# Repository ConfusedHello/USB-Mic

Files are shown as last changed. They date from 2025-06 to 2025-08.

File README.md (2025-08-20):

# VOXMIC - A DIY Studio-Quality USB-C Microphone
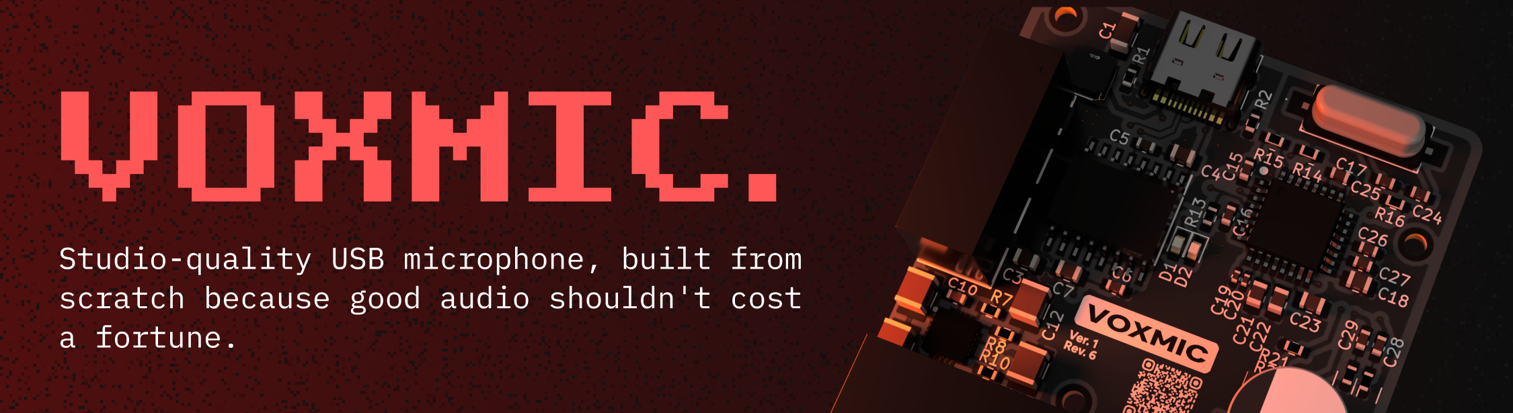
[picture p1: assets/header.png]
header

[Film lights](https://github.com/ConfusedHello/Videography-Light/tree/main) shouldn't be so insanely expensive, but you know what else shouldn't be either? A quality microphone. VoxMic is a completely DIY mic I've designed for the Hack Club [Highway to Hardware](https://highway.hackclub.com/) program!

**QUICK WARNING: This WILL NOT WORK without the bodged fixes** [*more information here*](https://www.reddit.com/r/electronics/comments/1mqmphi/comment/n9i0p1c/?context=3)

This is definitely the largest project I've ever worked on - Version 1 along has gone though **6 entire revisions** just to get to where it is now. *V2 is in the works!!!*

For details about the design process or other information, check out the [development journal](https://highway.hackclub.com/projects/ConfusedHello/USB-Mic). A local copy is available in [JOURNAL.md](https://github.com/ConfusedHello/USB-Mic/blob/main/JOURNAL.md).

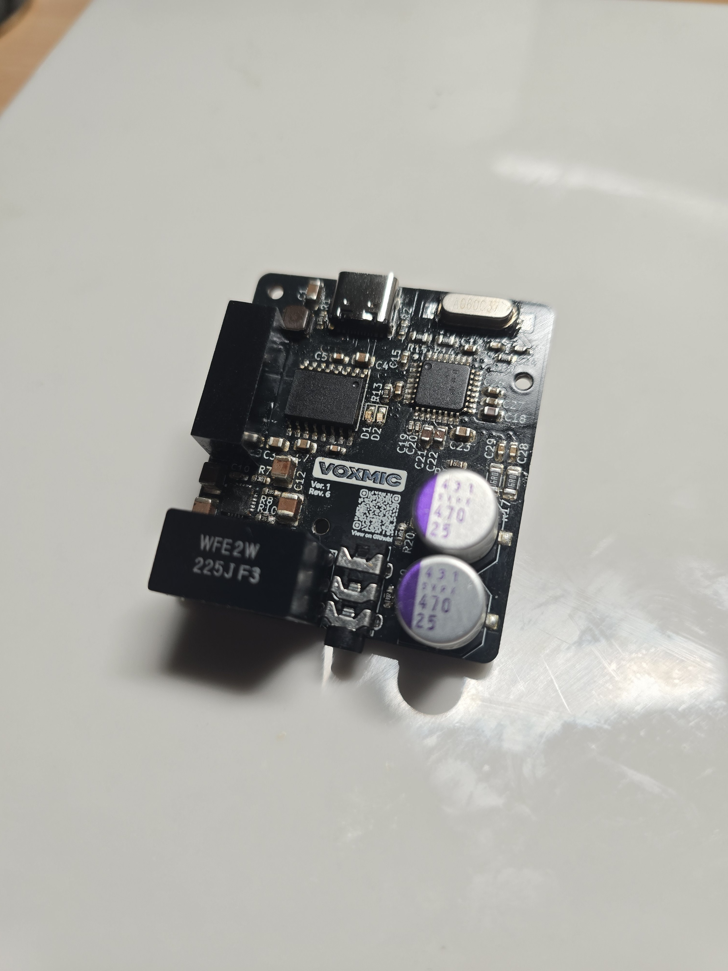
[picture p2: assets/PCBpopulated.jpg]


## The Design
Here's a quick diagram of the main components on the PCB~  
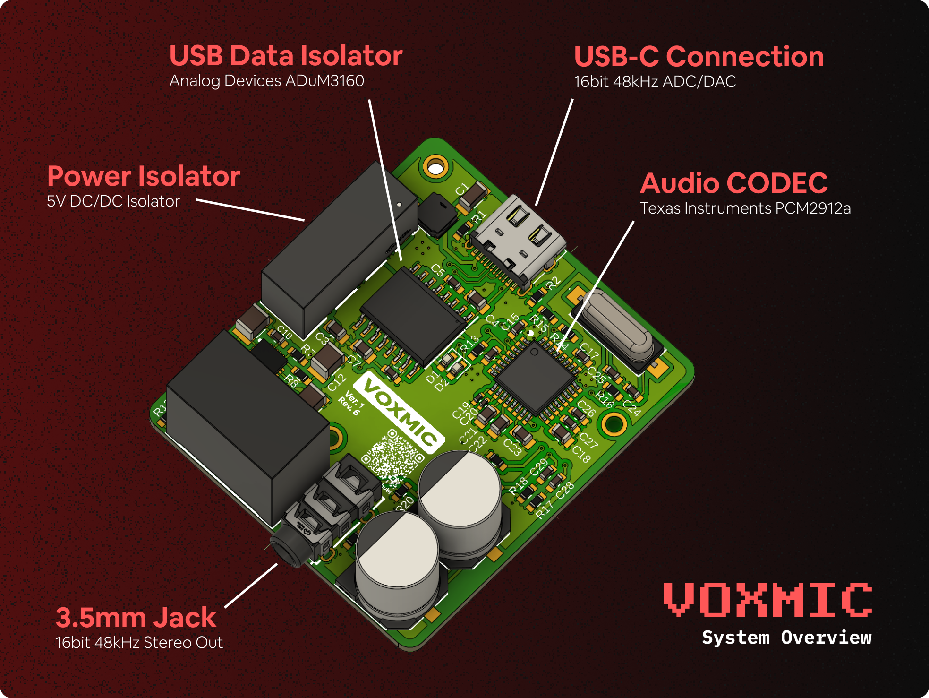
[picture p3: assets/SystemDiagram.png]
Diagram


As well as the design for the PCB!  
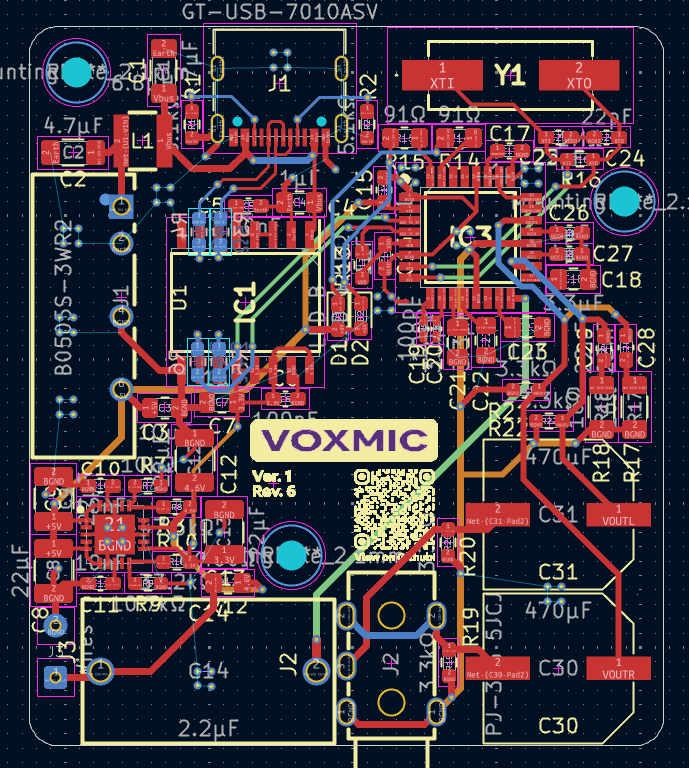
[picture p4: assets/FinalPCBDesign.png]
PCB Design

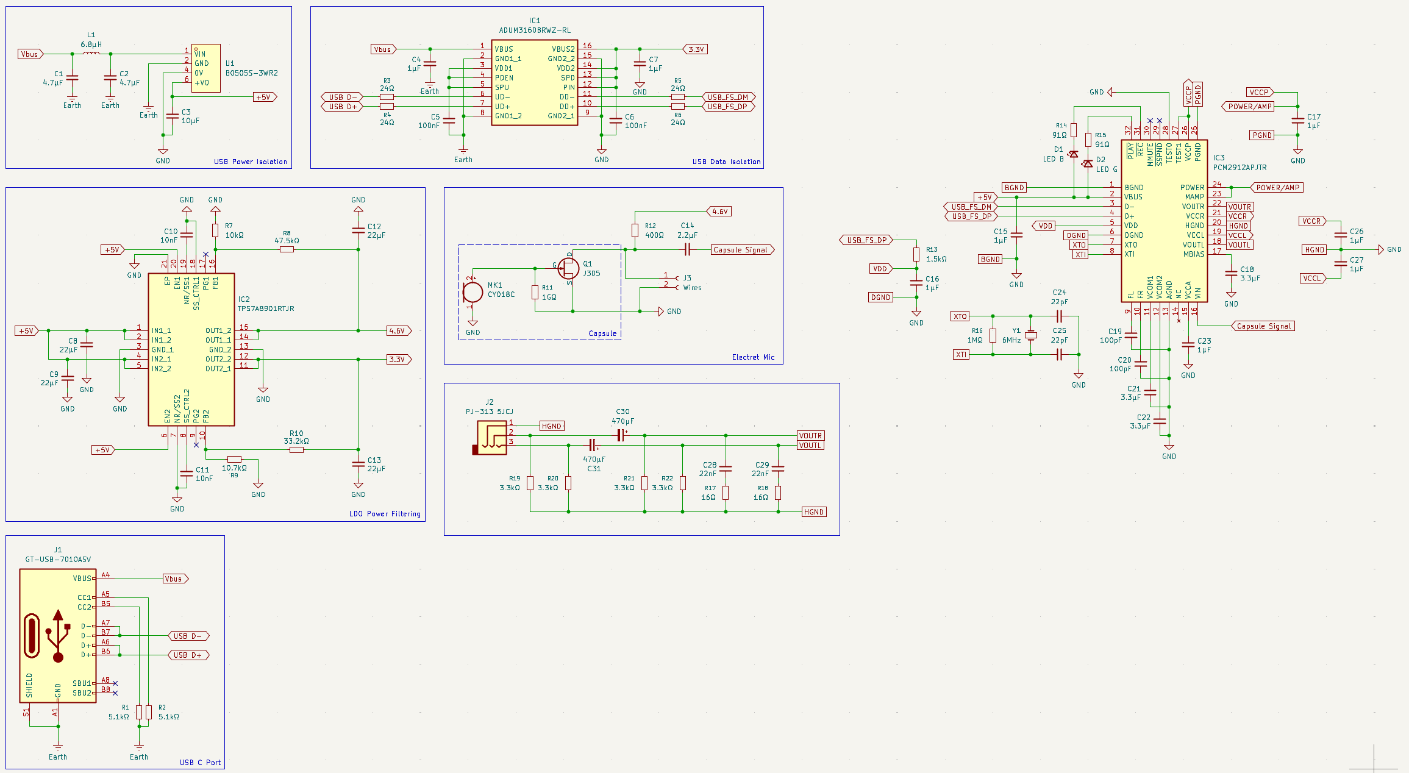
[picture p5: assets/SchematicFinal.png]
PCB Schematic


And a quick image of the case-  
<details>
<summary>Click to expand/collapse</summary>
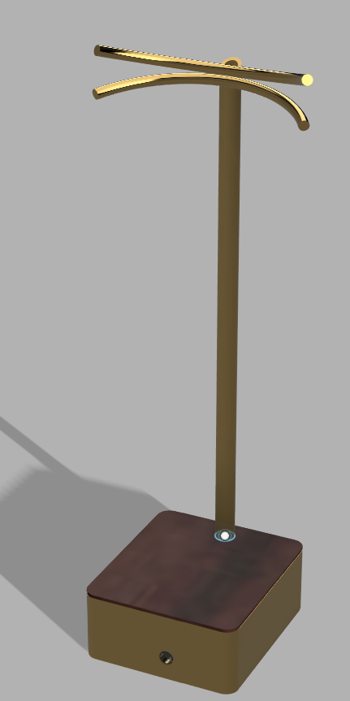
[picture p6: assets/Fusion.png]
CAD Render

</details>

## Bill of Materials
Also available in .csv format in [BOM.csv](https://github.com/ConfusedHello/USB-Mic/blob/main/BOM.csv)!

|Item |Qty.|Price (USD)|Ext. (USD)|Link |
|---|----|---|---|---|
|C14663 |100 |0.0024 |0.24 |https://lcsc.com/product-detail/multilayer-ceramic-capacitors-mlcc-smd-smt_yageo-cc0603krx7r9bb104_C14663.html |
|C21122 |50  |0.0042 |0.21 |https://lcsc.com/product-detail/multilayer-ceramic-capacitors-mlcc-smd-smt_samsung-electro-mechanics-cl10b223kb8nnnc_C21122.html  |
|C22843 |100 |0.0011 |0.11 |https://lcsc.com/product-detail/chip-resistor-surface-mount_uni-royal-uniroyal-elec-0603waf1501t5e_C22843.html |
|C23003 |100 |0.0011 |0.11 |https://lcsc.com/product-detail/chip-resistor-surface-mount_uni-royal-uniroyal-elec-0603waf3322t5e_C23003.html |
|C28323 |20  |0.0092 |0.18 |https://lcsc.com/product-detail/multilayer-ceramic-capacitors-mlcc-smd-smt_samsung-electro-mechanics-cl21b105kbfnnne_C28323.html  |
|C51205 |10  |0.0337 |0.34 |https://lcsc.com/product-detail/multilayer-ceramic-capacitors-mlcc-smd-smt_samsung-electro-mechanics-cl31b475kbhnnne_C51205.html  |
|C59782 |100 |0.005 |0.5 |https://lcsc.com/product-detail/multilayer-ceramic-capacitors-mlcc-smd-smt_samsung-electro-mechanics-cl10b105ko8nnnc_C59782.html  |
|C95841 |10  |0.0232 |0.23 |https://lcsc.com/product-detail/multilayer-ceramic-capacitors-mlcc-smd-smt_samsung-electro-mechanics-cl21b106koqnnne_C95841.html  |
|C98220 |100 |0.0011 |0.11 |https://lcsc.com/product-detail/chip-resistor-surface-mount_yageo-rc0603fr-0710kl_C98220.html |
|C100042 |100 |0.0022 |0.22 |https://lcsc.com/product-detail/multilayer-ceramic-capacitors-mlcc-smd-smt_yageo-cc0603krx7r9bb103_C100042.html |
|C105578 |100 |0.0012 |0.12 |https://lcsc.com/product-detail/chip-resistor-surface-mount_yageo-rc0603fr-071ml_C105578.html |
|C105620 |100 |0.0024 |0.24 |https://lcsc.com/product-detail/multilayer-ceramic-capacitors-mlcc-smd-smt_yageo-cc0603jrnpo9bn220_C105620.html |
|C108078 |100 |0.0012 |0.12 |https://lcsc.com/product-detail/chip-resistor-surface-mount_yageo-rc0603fr-073k3l_C108078.html |
|C153298 |20  |0.0303 |0.61 |https://lcsc.com/product-detail/chip-resistor-surface-mount_ever-ohms-tech-tr0805b400rp0525z_C153298.html |
|C178482 |1 |0.3897 |0.39 |https://lcsc.com/product-detail/polypropylene-film-capacitors-cbb_panasonic-ecwfe2w225j_C178482.html |
|C180908 |1 |2.0425 |2.04 |https://lcsc.com/product-detail/voltage-regulators-linear-low-drop-out-ldo-regulators_texas-instruments-tps7a8901rtjr_C180908.html|
|C284149 |1 |4.8716 |4.87 |https://lcsc.com/product-detail/isolated-usb-ics_analog-devices-adum3160brwz-rl_C284149.html |
|C309062 |4 |0.1383 |0.55 |https://lcsc.com/product-detail/multilayer-ceramic-capacitors-mlcc-smd-smt_samsung-electro-mechanics-cl32b226kajnnne_C309062.html |
|C454276 |2 |1.1425 |2.29 |https://lcsc.com/product-detail/polymer-aluminum-capacitors_panasonic-25svpk470m_C454276.html |
|C475497 |1 |4.3489 |4.35 |https://lcsc.com/product-detail/audio-interface-ics_texas-instruments-pcm2912apjtr_C475497.html |
|C541383 |100 |0.0011 |0.11 |https://lcsc.com/product-detail/multilayer-ceramic-capacitors-mlcc-smd-smt_yageo-cc0402krx7r8bb101_C541383.html |
|C596830 |5 |0.3215 |1.61 |https://lcsc.com/product-detail/crystals_abracon-llc-abls2-6-000mhz-d4y-t_C596830.html |
|C668607 |5 |0.0783 |0.39 |https://lcsc.com/product-detail/audio-connectors_shou-han-pj-313-5jcj_C668607.html |
|C965804 |100 |0.0044 |0.44 |https://lcsc.com/product-detail/led-indication-discrete_xinglight-xl-1608ugc-04_C965804.html |
|C965807 |100 |0.0035 |0.35 |https://lcsc.com/product-detail/led-indication-discrete_xinglight-xl-1608ubc-04_C965807.html |
|C2907018 |100 |0.0009 |0.09 |https://lcsc.com/product-detail/chip-resistor-surface-mount_fojan-frc0603f24r0ts_C2907018.html |
|C2907044 |100 |0.001 |0.1 |https://lcsc.com/product-detail/chip-resistor-surface-mount_fojan-frc0603f5101ts_C2907044.html |
|C2933225 |100 |0.001 |0.1 |https://lcsc.com/product-detail/chip-resistor-surface-mount_fojan-frc0603f4752ts_C2933225.html |
|C2933510 |100 |0.0018 |0.18 |https://lcsc.com/product-detail/chip-resistor-surface-mount_fojan-frc0805f91r0ts_C2933510.html |
|C2933610 |100 |0.0029 |0.29 |https://lcsc.com/product-detail/chip-resistor-surface-mount_fojan-frc1206f16r0ts_C2933610.html |
|C2988369 |5 |0.0805 |0.4 |https://lcsc.com/product-detail/usb-connectors_g-switch-gt-usb-7010asv_C2988369.html |
|C5153968 |100 |0.0009 |0.09 |https://lcsc.com/product-detail/chip-resistor-surface-mount_fojan-frc0603f1072ts_C5153968.html |
|C7393948 |20  |0.022 |0.44 |https://lcsc.com/product-detail/multilayer-ceramic-capacitors-mlcc-smd-smt_cctc-tcc0805x7r335k250ft_C7393948.html |
|C7500927 |1 |1.2079 |1.21 |https://lcsc.com/product-detail/isolated-power-modules_evisun-b0505s-3wr2_C7500927.html |
|C16197249 |5 |0.0579 |0.29 |https://lcsc.com/product-detail/power-inductors_yjycoin-yhnr4020-6r8m_C16197249.html |
|LCSC Shipping |1 |10.62 |10.62 |https://lcsc.com |
|CY018C |1 |30.00 |30.00 |https://www.alibaba.com/product-detail/797-Audio-CY018C-Custom-26mm-3um_1600884124178.html |
|J305 |1 |7.54 |7.54 |https://au.mouser.com/ProductDetail/InterFET/J305 |
|MOX-400231007JE |1 |10.29 |10.29 |https://au.mouser.com/ProductDetail/Ohmite/MOX-400231007JE |
|Mouser Shipping |1 |15.67 |15.67 |https://au.mouser.com |
|JLCPCB Board |1 |2.00 |2.00 |https://jlcpcb.com/ |
|JLCPCB Board Stencil |1 |7.00 |7.00 |https://jlcpcb.com/ |
|JLCPCB Shipping |1 |21.22 |21.22 |https://jlcpcb.com/ |
|Brass Tube |1 |2.21 |2.21 |https://www.aliexpress.com/item/1005005239798226.html |
|Brass Rod |6 |12.52 |12.52 |https://www.aliexpress.com/item/1005008645247905.html |
|2x100x200mm Brass Sheet|1 |17.38 |17.38 |https://www.aliexpress.com/item/1005007129408124.html |
|Steel Mesh |1 |2.80 |2.80 |https://www.aliexpress.com/item/1005003090693763.html |
|Brass Wire |1 |3.36 |3.36 |https://www.aliexpress.com/item/1005007182450013.html |
|Wood Veneer |1 |8.04 |8.04 |https://www.aliexpress.com/item/1005007643104919.html |

Total (USD): $174.57

## Notes for v2
- Capacitive touch button for muting
- Better status signalling to user
- Upgrade ADC/DAC

<hr>

Made with ❤️ by [@ConfusedHello](https://github.com/confusedhello)

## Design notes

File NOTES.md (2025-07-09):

Notes:

Get extra resistors for R11 and R12 to calibrate output
Get extra resistors for (cap biasing/supply)

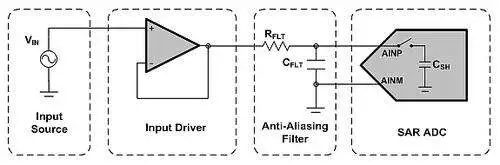
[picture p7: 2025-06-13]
assets/Proccess.jpg

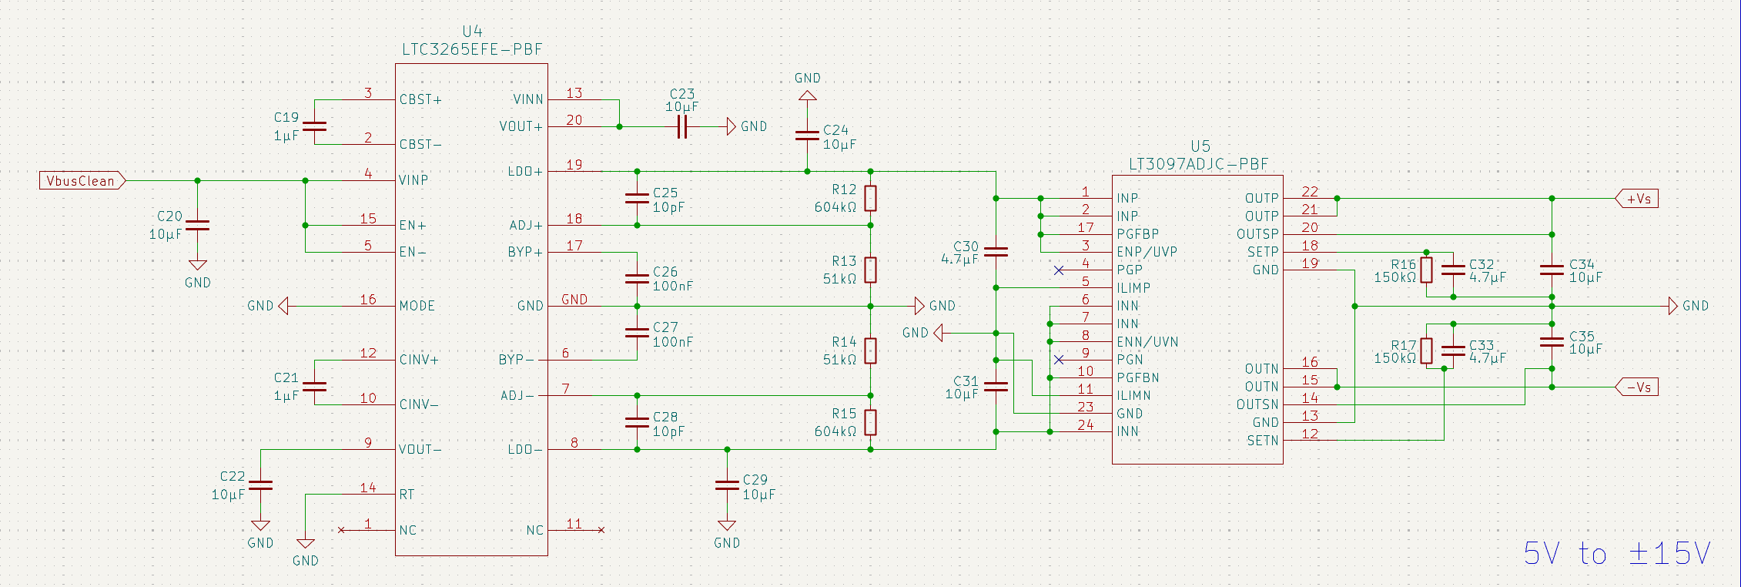
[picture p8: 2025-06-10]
assets/Rev1OPPOWER.png

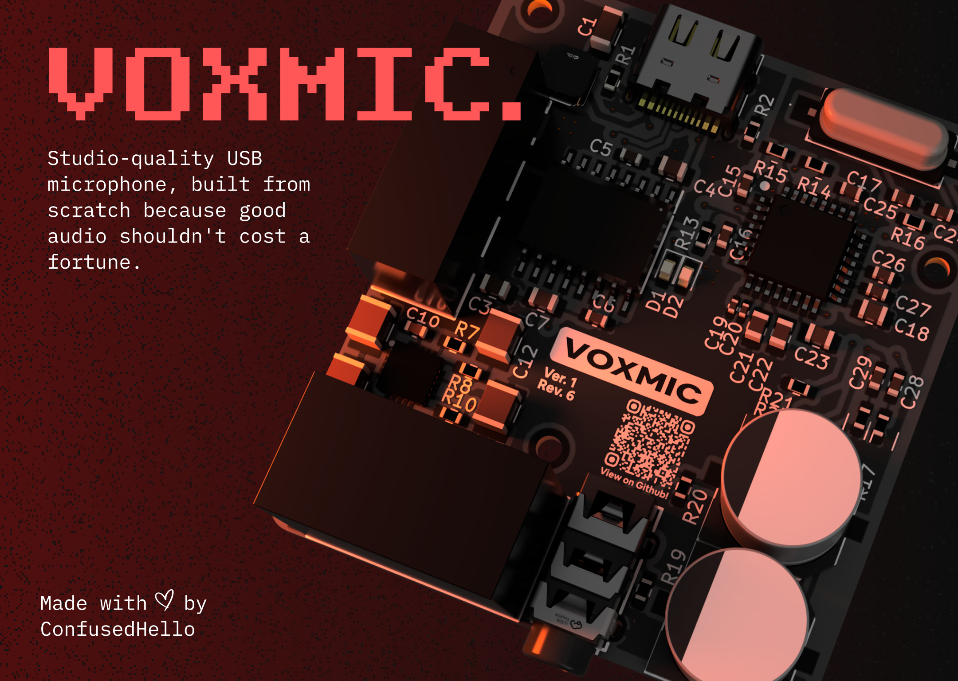
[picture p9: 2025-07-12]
assets/Slack Thumbnail.png

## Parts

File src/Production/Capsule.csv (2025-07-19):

Reference | Value | Footprint | Description | Qty | Link
MK1 | CY018C |  | Microphone Capsule | 1 | https://www.alibaba.com/product-detail/797-Audio-CY018C-Custom-26mm-3um_1600884124178.html
Q1 | J305 |  | N-JFET Transistor | 1 | https://au.mouser.com/ProductDetail/InterFET/J305
R11 | 1GΩ |  | Bias Resistor | 1 | https://au.mouser.com/ProductDetail/Ohmite/MOX-400231007JE

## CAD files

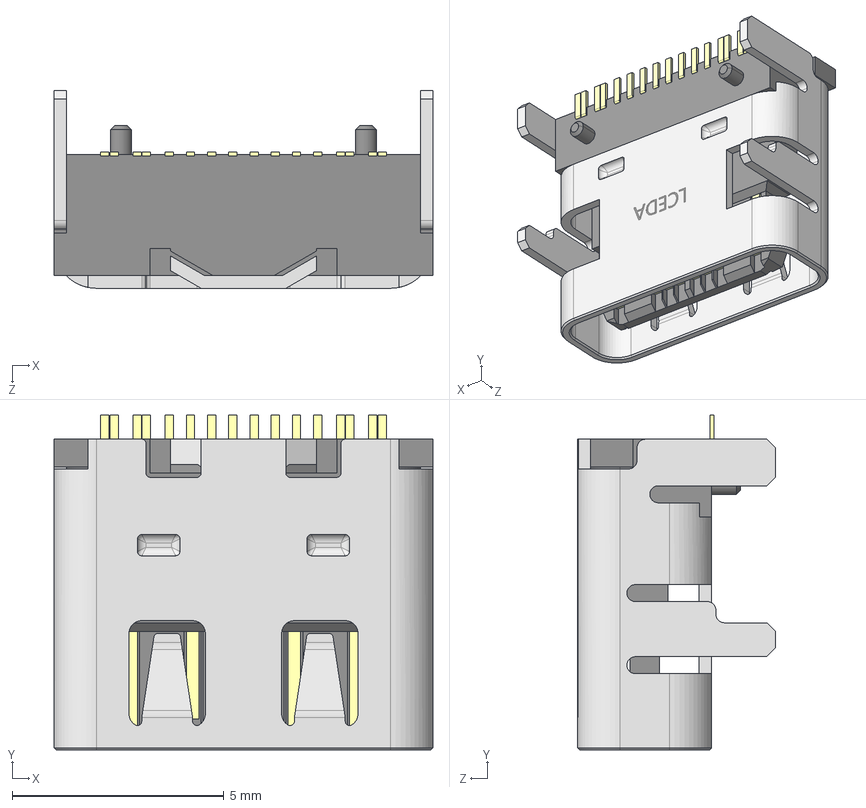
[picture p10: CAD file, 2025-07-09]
src/PCB/footprints/models/USB-C-SMD_G-SWITCH_GT-USB-7010ASV.step
8.94 x 7.90 x 4.66 mm

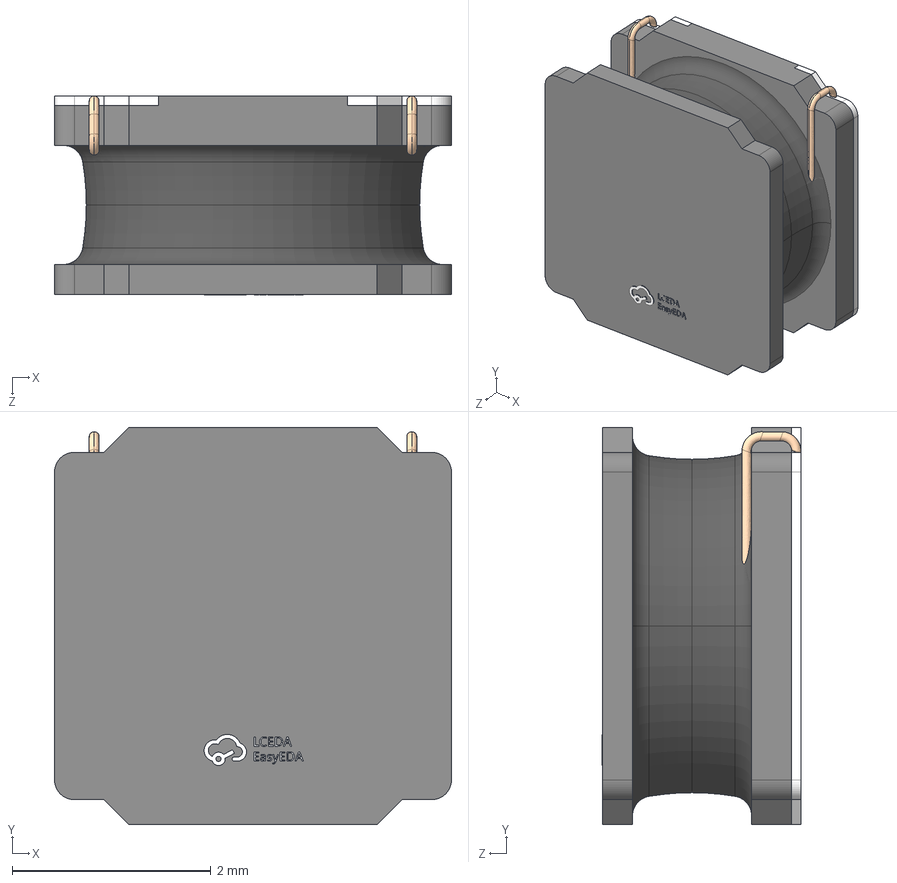
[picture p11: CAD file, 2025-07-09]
src/PCB/footprints/models/IND-SMD_L4.0-W4.0_YHNR4020.step
4.00 x 4.00 x 2.01 mm

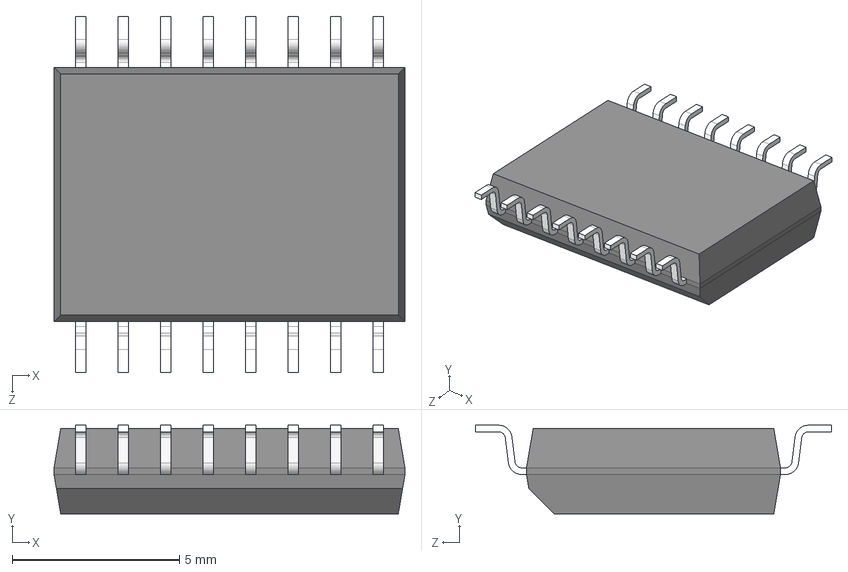
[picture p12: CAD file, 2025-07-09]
src/PCB/footprints/models/ADUM3160BRWZ-RL.stp
10.5 x 2.65 x 10.7 mm

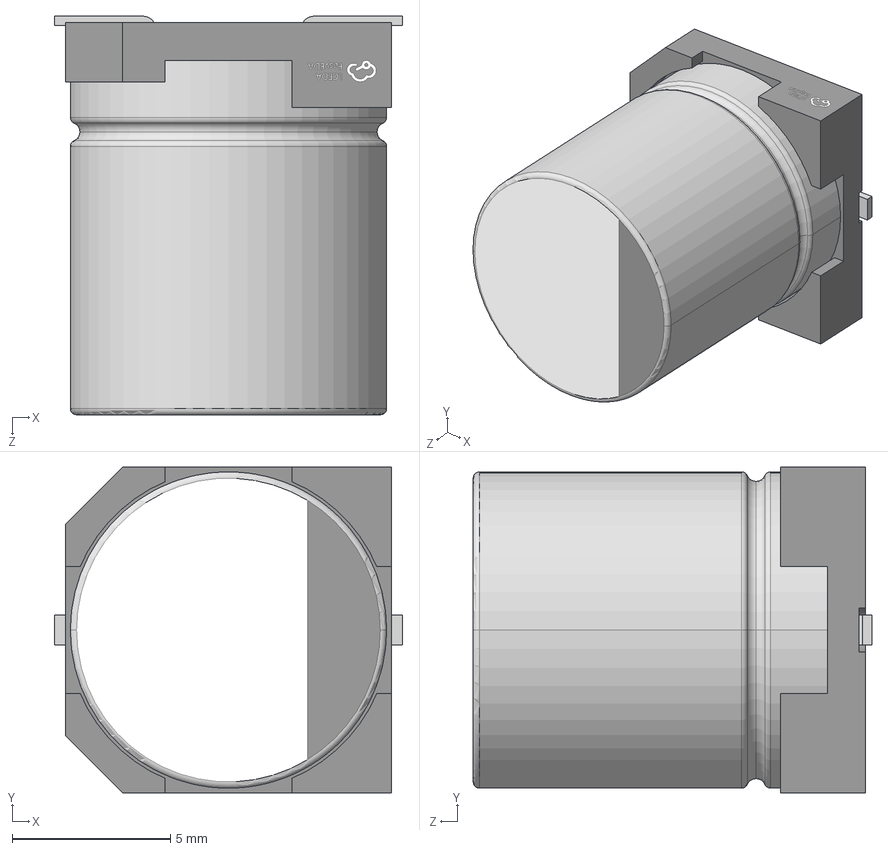
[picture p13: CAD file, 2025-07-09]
src/PCB/footprints/models/CAP-SMD_BD10.0-L10.3-W10.3-LS11.0-FD-1.step
11.0 x 10.3 x 12.6 mm

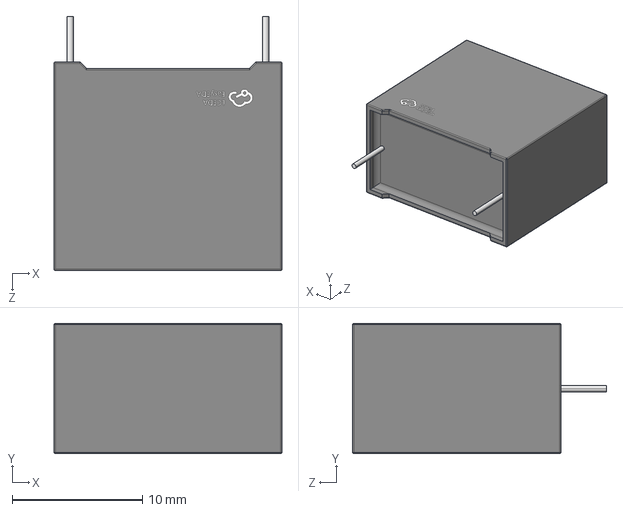
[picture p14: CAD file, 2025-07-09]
src/PCB/footprints/models/CAP-TH_L17.5-W10.0-H16.0-P15.0.step
17.5 x 10.0 x 19.5 mm

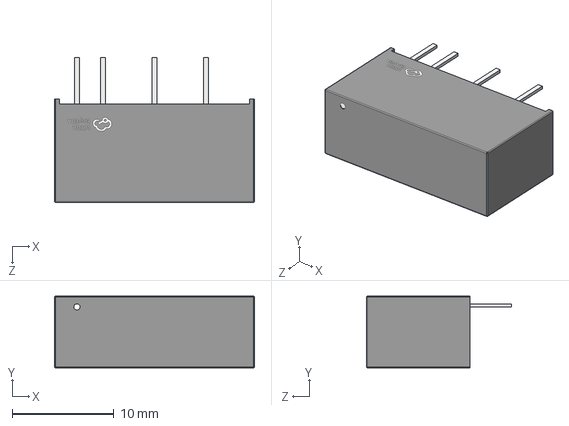
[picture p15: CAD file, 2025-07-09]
src/PCB/footprints/models/PWRM-TH_BXXXXS-3WR2.step
19.6 x 7.05 x 14.3 mm

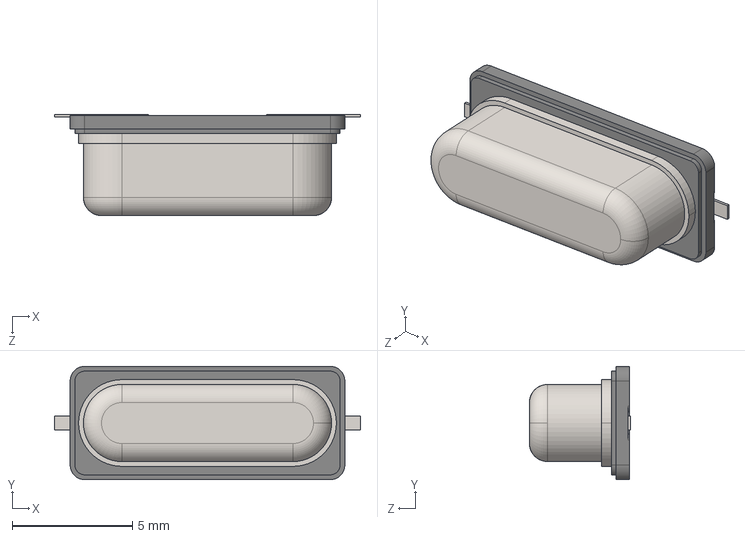
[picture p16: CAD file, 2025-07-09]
src/PCB/footprints/models/ABLS2-6.000MHZ-D4Y-T.stp
12.7 x 4.70 x 4.20 mm

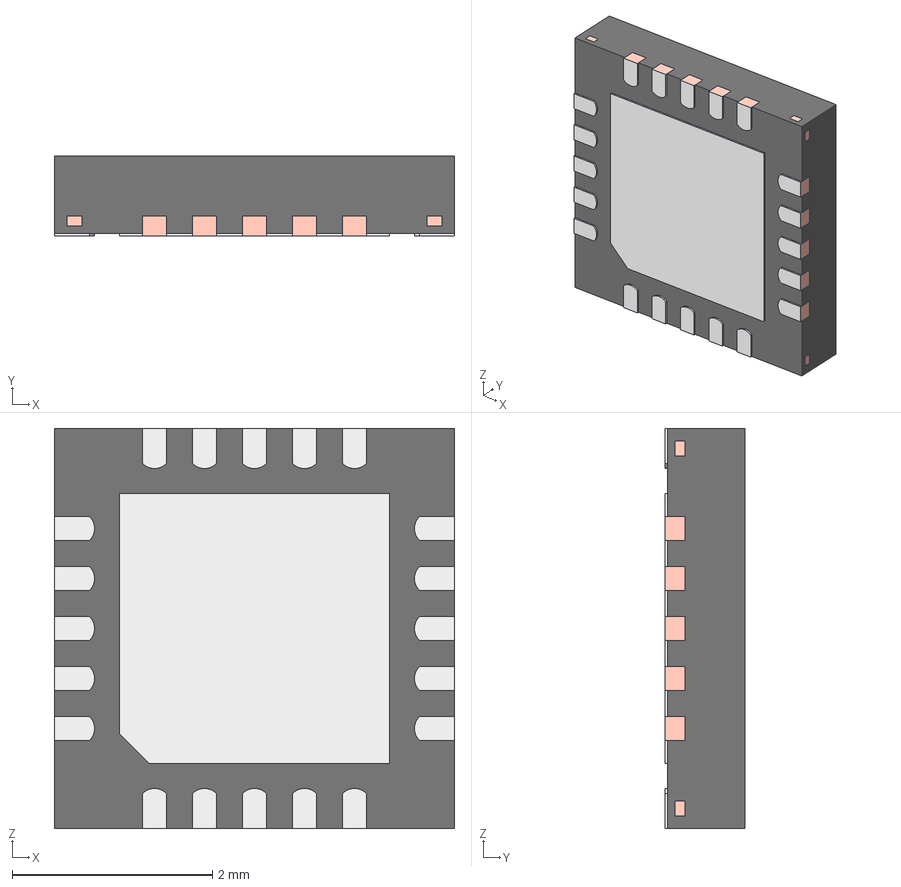
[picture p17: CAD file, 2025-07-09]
src/PCB/footprints/models/TPS7A8901RTJT.stp
4.00 x 0.8 x 4.00 mm
FRAME
PIN1_AREA

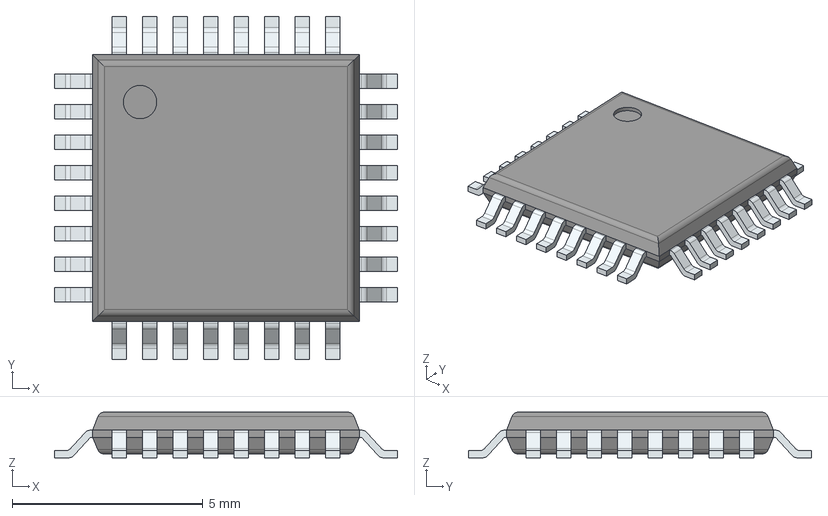
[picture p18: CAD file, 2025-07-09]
src/PCB/footprints/models/PCM2912APJTR.stp
9.00 x 9.00 x 1.20 mm
PinsArrayLR
PinsArrayTB

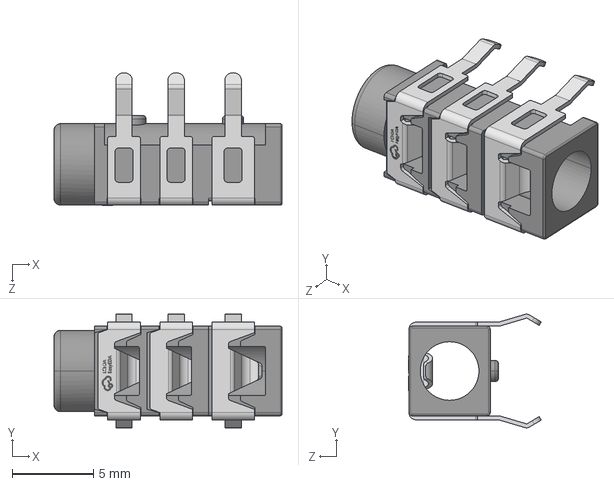
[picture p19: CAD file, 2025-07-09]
src/PCB/footprints/models/AUDIO-TH_PJ-313_5JCJ.step
14.0 x 6.98 x 8.14 mm

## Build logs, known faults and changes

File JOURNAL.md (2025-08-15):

---
title: "USB Mic"
author: "ConfusedHello"
description: "A DIY USB Microphone!"
created_at: "2024-05-22"
---

**Total time spent: 142hrs**

## August 9th
Summary: Pain.

Spent MANY MANY hours trying to solder everything together with a hot air rework station and a hot plate stolen from the chemistry department. 

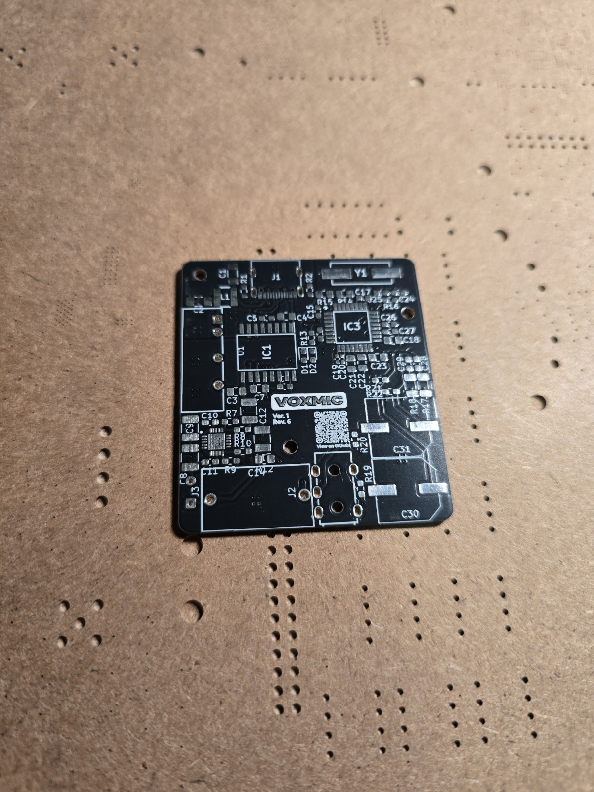
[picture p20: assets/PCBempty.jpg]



After finnicking with the dead small components for around 6 hours and screwing up 2 boards, de-soldering, and re-soldering , I plugged it in... for it to not work. USB wasn't working, and half the voltage regulator wasn't working from what I assumed was a bad join. I ended up replacing the voltage regulator with... a Xiao RP2040 (a technique I pioneered during Undercity when we had no 3.3V regs). After much pain (yes this was a very painful day), I decided that the USB isolator might be the issue, so I yanked it off, bridged the connections, and bodged a pullup to the D+ line.

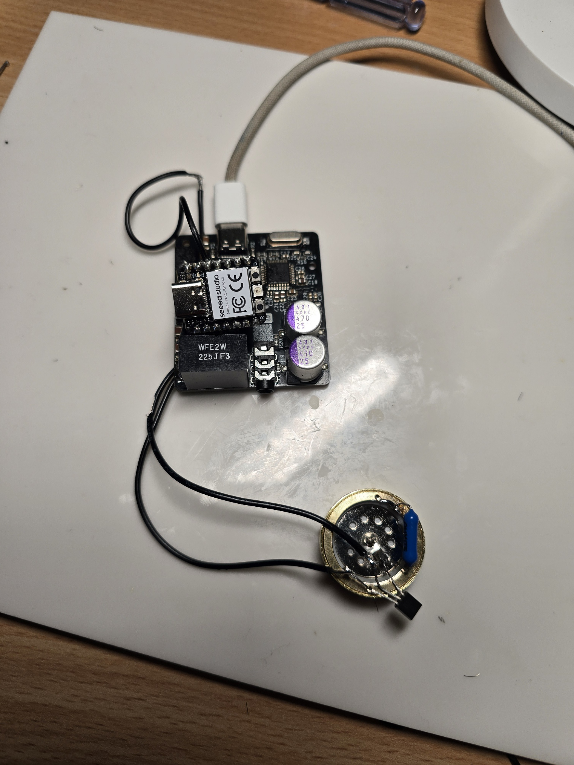
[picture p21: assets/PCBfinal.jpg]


And it... sorta works! The main issue (something I worried about during the design) was the lack of a preamp. It would not work unless I had the capsule almost *inside* my mouth. And since my brass sheet never arrived (thank you Aliexpress) I was stuck with everything but the materials for the main body. Hopefully this is okay until I can get parts!

**Time spent: 10hrs**

## July 10th
Last day before Undercity and just spent some time finalising some renders for submission!

## July 3rd-9th
Submitted another 10 point project in the last week! The last few days I've returned to working on the PCB, and finalising component selections. I've also thrown together a quick model of the case and some renders! All the lovely renders are available in the [README](https://github.com/ConfusedHello/USB-Mic) on Github!

Here's a sneak peak of the PCB~
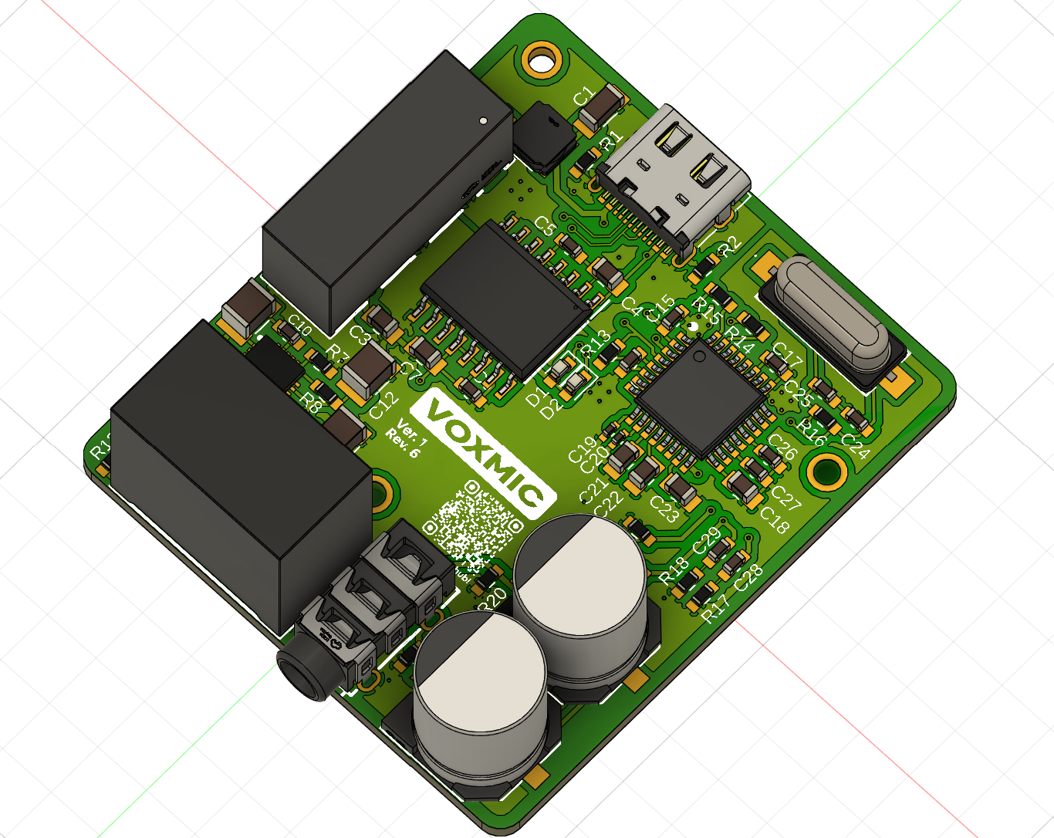
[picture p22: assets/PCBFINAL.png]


**Time spent: 16hrs**

## June 27th
HELLO AGAIN THE SCHEMATIC IS FINISHED

**Time spent: 3hrs**

## June 26th
Finished schematic, will do final review tomorrow. Have started working on selecting footprints for SMD components.

**Time spent: 5hrs**

## June 25th
One business week later - I'm partially back! My gimbal has been submitted successfully and the invite to Undercity has been received!! Spent a little time today finishing up the schematic. Realistically I'll work on the PCB tomorrow - its the final week of Term 3 so prepare for some 12hr days over the holidays.

**Time spent: 4hrs**

## June 20th
Significant progress today! However, the project will be put on hold until next Tuesday due to school tests and SAT deadlines. Progress will be journaled next week!

**Time spent: 6hrs**

## June 19th
More simulation and math. Mostly images today!!
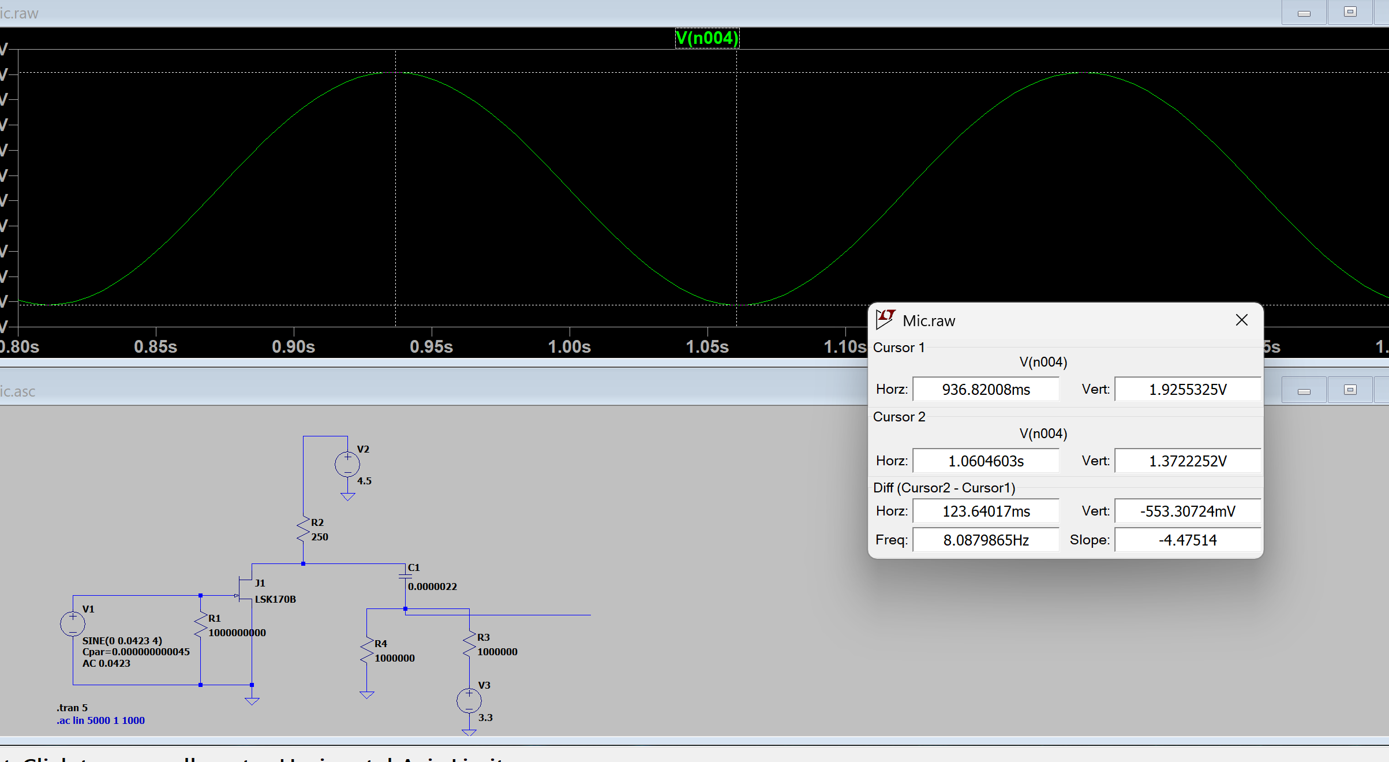
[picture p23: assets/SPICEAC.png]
SPICE

AC Analysis of the JFET output stage

With these results I made:
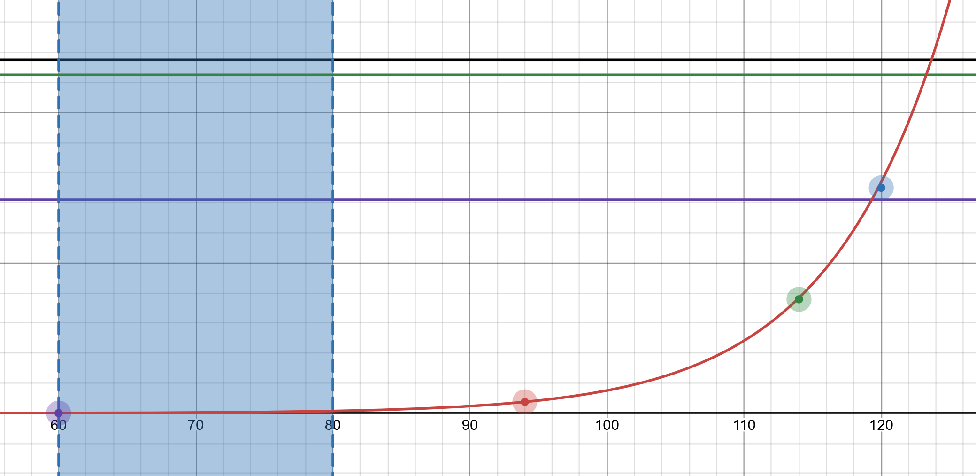
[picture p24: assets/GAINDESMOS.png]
DESMOS

Fig 1. dB to mV<sub>PP</sub> @Gain=1<sub>v/v</sub>

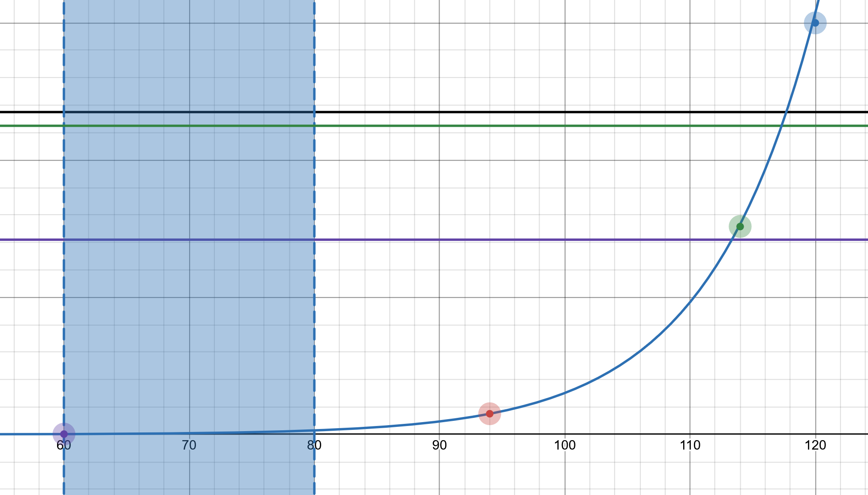
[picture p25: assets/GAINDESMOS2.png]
Desmos

Fig 2. dB to mV<sub>PP</sub> @Gain=2<sub>v/v</sub>

The purple line is the recommended max input voltage on the ADC input pins, the black line is the maximum voltage allowed, and the green is the clipping voltage of the op-amp when powered from the 4.5V supply. Honestly, I think going with no gain might actually be okay considering the +20dB amp + the -13/+36dB PGA.

Will look into choosing another N-JFET considering mine is $10... the J305 is looking pretty interesting though!

**Time spent: 10hrs**

## June 18th
Turns out making sure everything will *actually* work is difficult. Very difficult. Turns out the math behind making sure things don't explode isn't easy. In summary, over the last few days I've been revising each and every component of the microphone to make sure it's functional and well as non-explosive.

Have now moved onto consolidating values for the preamp stage. I've also done some SPICE simulations!
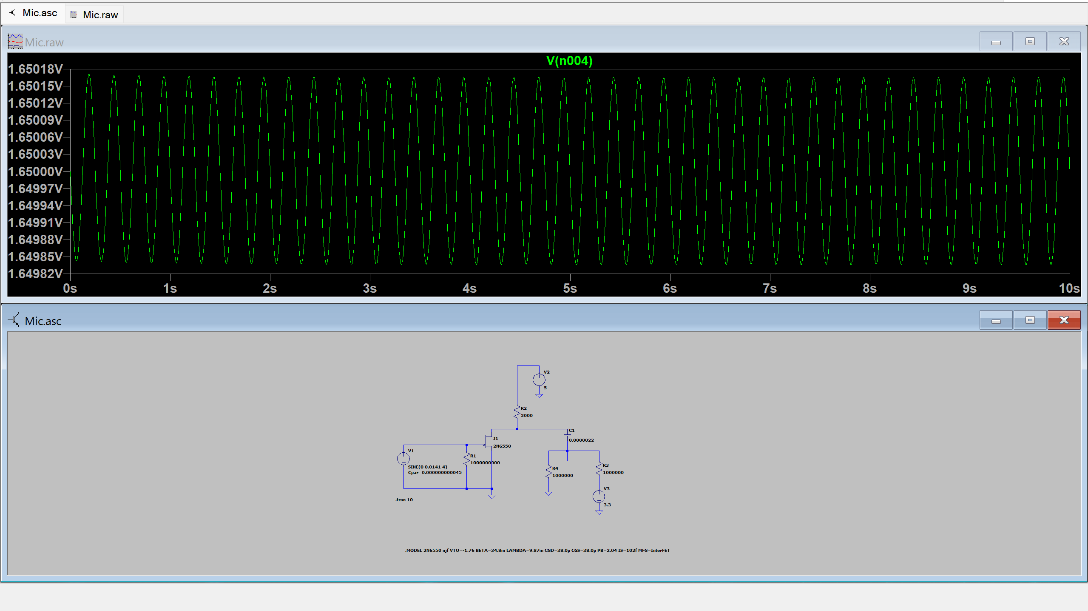
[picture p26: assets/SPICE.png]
SPICE


Busy week unfortunately - will try to work on as much as I can.

**Time spent: 8hrs**

## June 17th
Have been sick. Updates returning soon! Note to self: 14.1mV/Pa cap

## June 13th
Crazyy amount of work researching and on Rev. 4 - will finish off tomorrow. Also, the progression from Rev. 1 to 4 will be quite interesting to look back at...

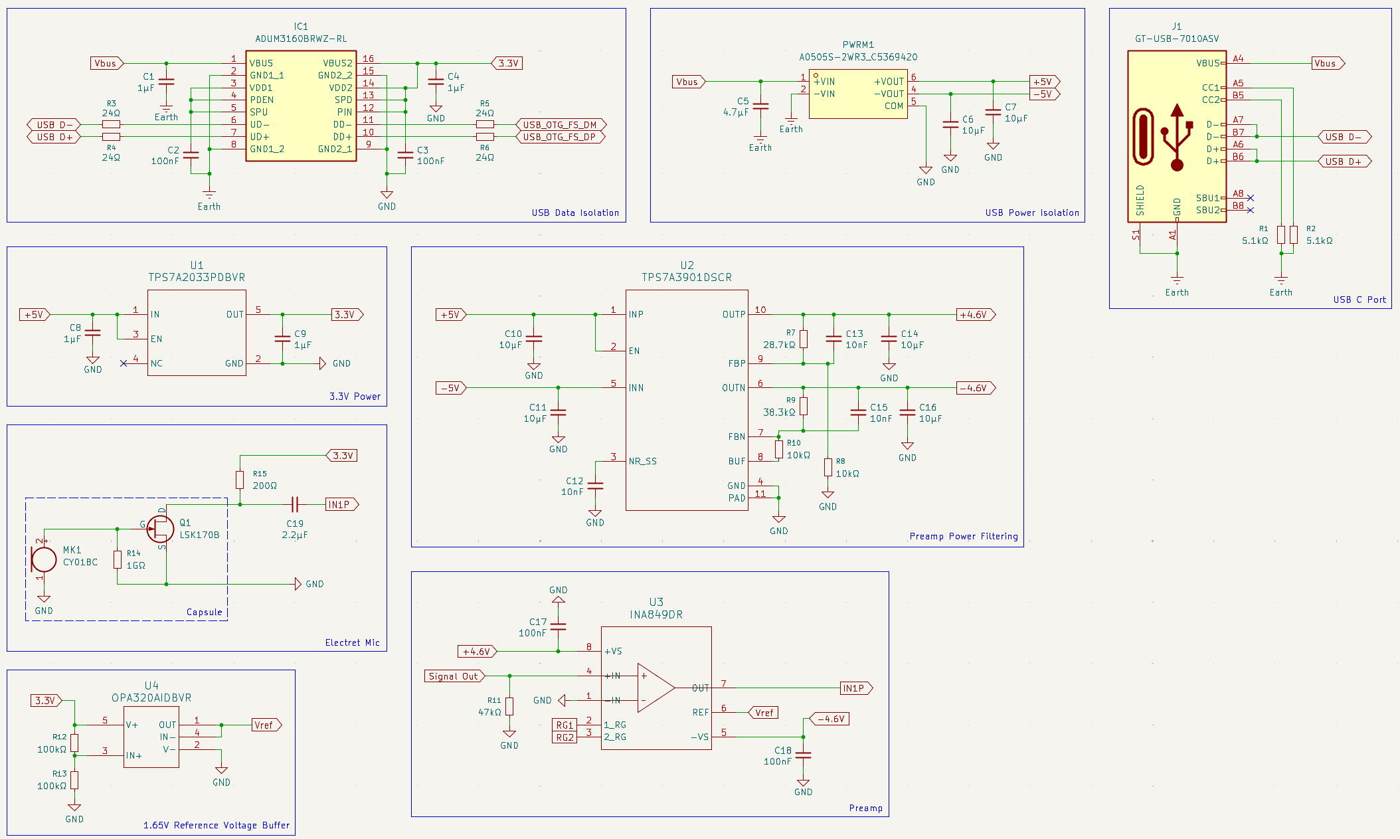
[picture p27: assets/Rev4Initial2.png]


**Time spent: 10hrs**

## June 12th
Summary of changes for Rev. 4:

- Add preamp (assumed TAA had PGA like it's I2C version - it doesn't)
- Add USB data and power isolation
- Add DC/DC converter + LDOs for preamp
- Fix floating STM32 pins
- Add ST-Link debug pins in case USB doesn't work

Hours and hours of research and reading datasheets behind this move. Also did begin working on some PCB design ideas as well as set up the STM32 CUBE IDE environment. Finishing off today's log with some screenshots.

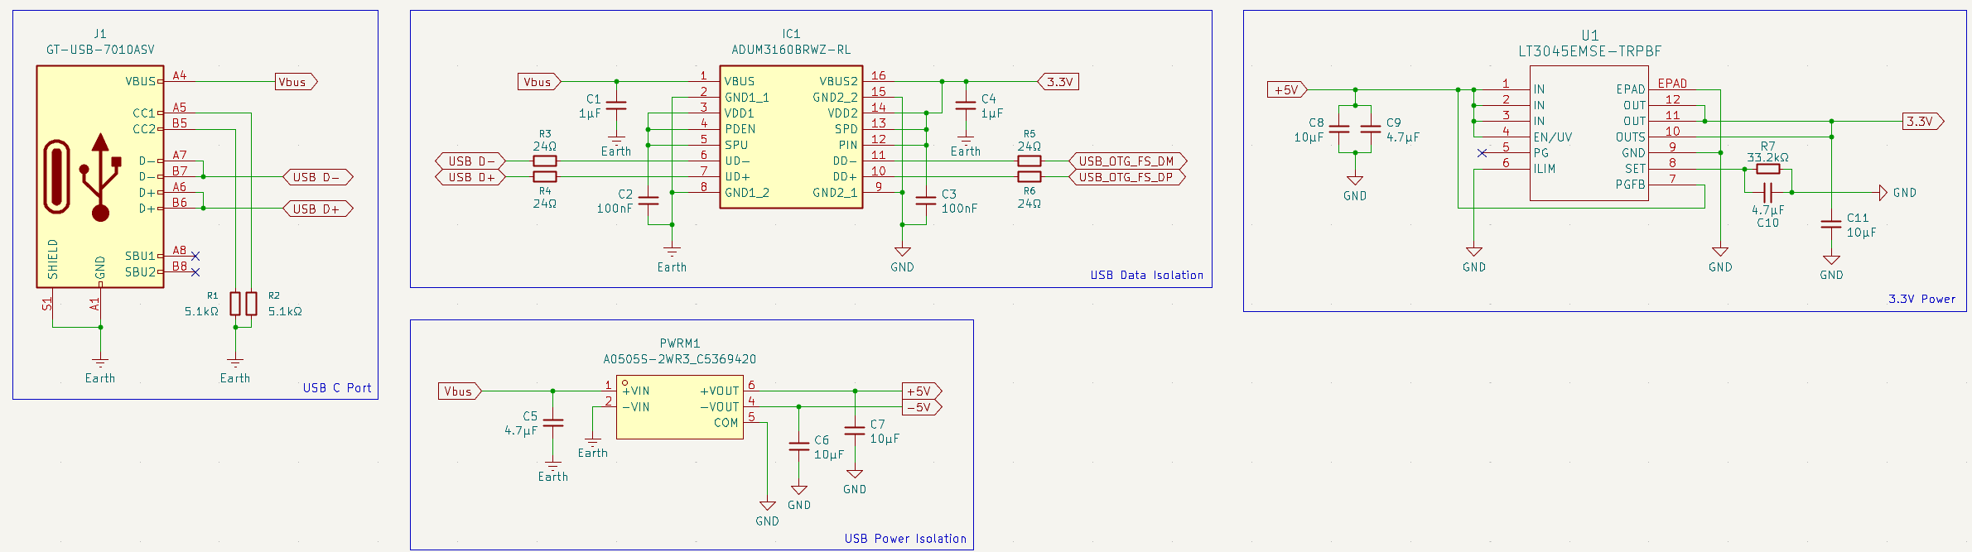
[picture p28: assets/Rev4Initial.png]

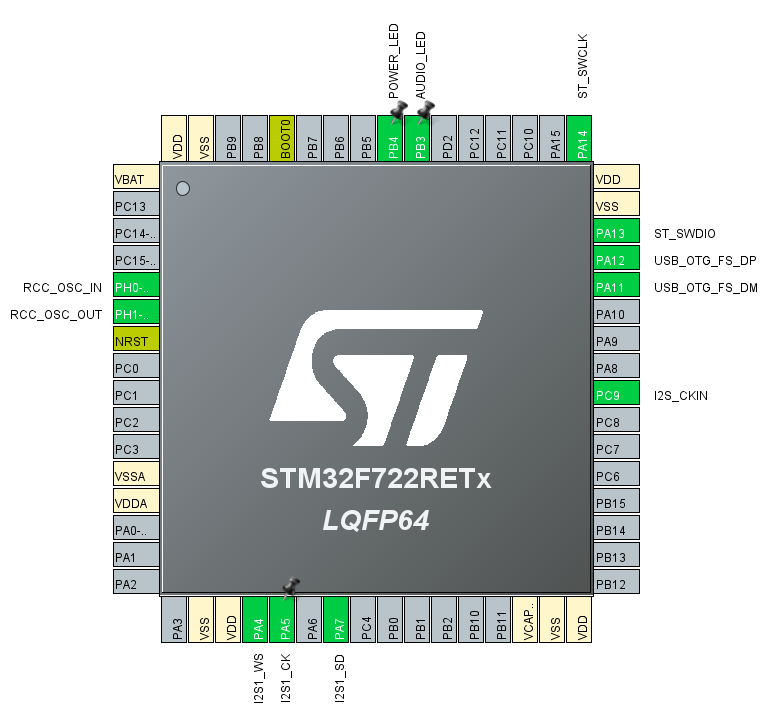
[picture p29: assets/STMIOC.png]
MCU Pinout


**Time spent: 9hrs**

## June 10th, 11th
Worked on the schematics for system today. I'm expecting Rev. 3 to be the final version of the schematic.

Thanks to the new STM32 microcontroller and ADC, the power circuity has been dumbed down even more! Since the 5V-ish Vbus only needs to go *down* to 3.3V, only the LT3045 will be needed to do all the power filtering!

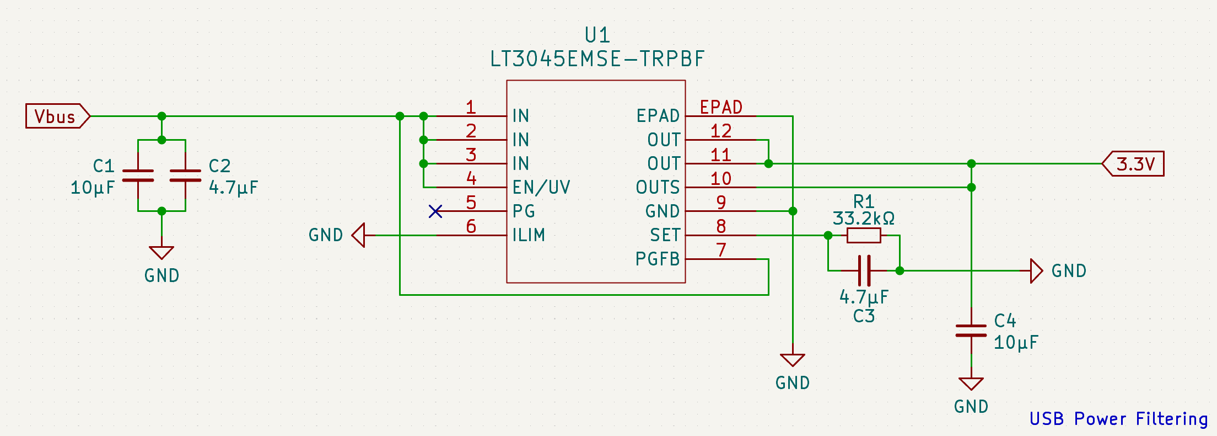
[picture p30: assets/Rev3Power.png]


Explaination soon:

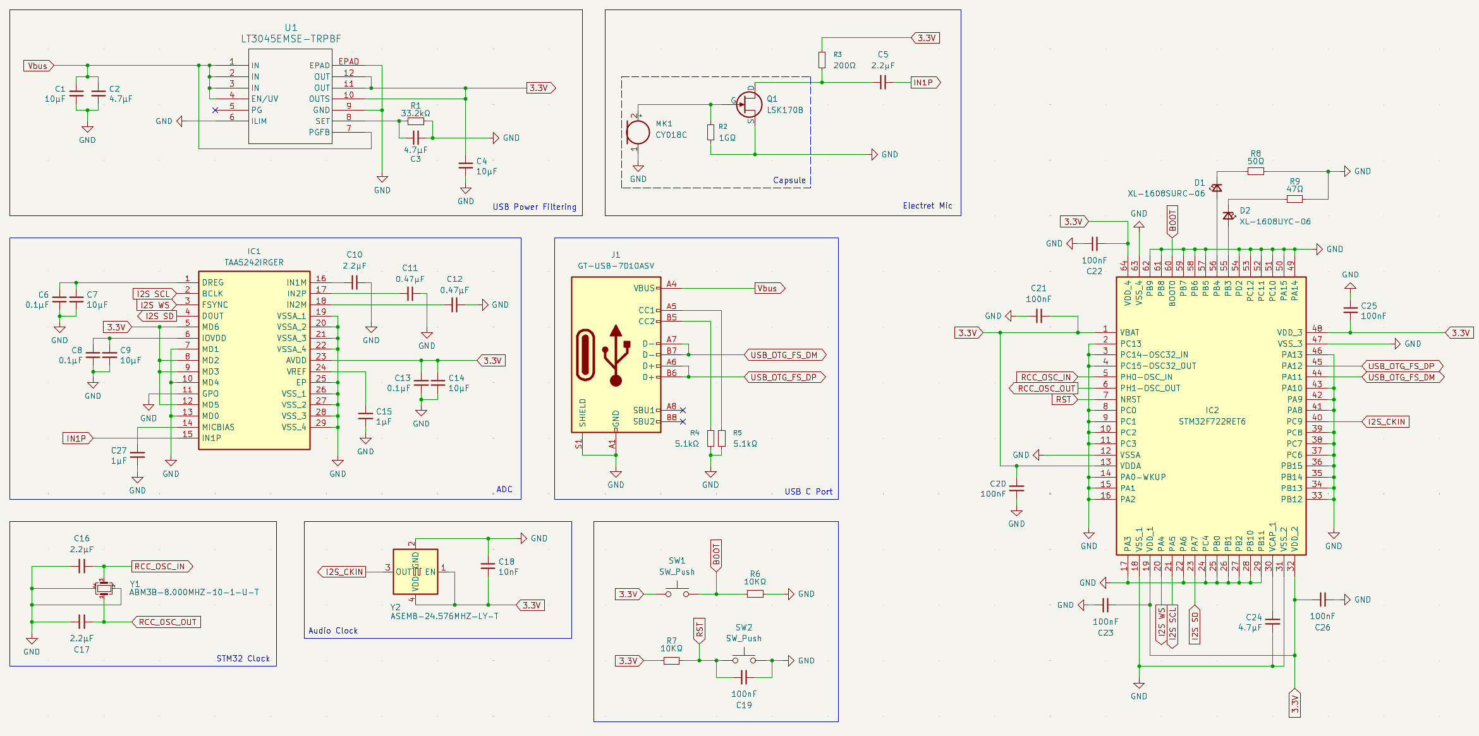
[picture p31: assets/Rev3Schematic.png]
Schematic


**Time spent: 14hrs**

## June 7th, 8th, 9th
Work over the long weekend! Lots of research (AMA) and thinking... thinking... thinking... In conclusion - time for a 3rd revision!

**Time spent: 8hrs**

## June 4th, 5th, 6th
A lot of research looking for USB-chips..., STM32 Audio Class implementations... So much time, so much pain.

IN SUMMARY

- XMOS (the standard higher-end audio chip company) IS EXPENSIVE AND PAINFUL TO USE. Absolute no-go.
- ADC/DAC USB chips from realtech, cmedia, cirrius etc. which are typically used in laptops aren't very easy to get a hold of... and also kinda suck. And outside of these, USB devices are non-existent.

As such, we'll be going the STM32 route! There's middleware for USB Audio as well as I2S communication, so the programming should be... significantly challenging but not impossible.

**Time spent: 9hrs**

## June 2nd, 3rd
Reviewed the schematics over the last two days. A few changes have been made so, I figure this is officially Rev. 2

Firstly, the preamp+capsule didn't actually make any sense (TI what are you doing) so I've transitioned to a more traditional preamp. I've also added in variable pickup using a two switches connected to the front and back diaphrams.
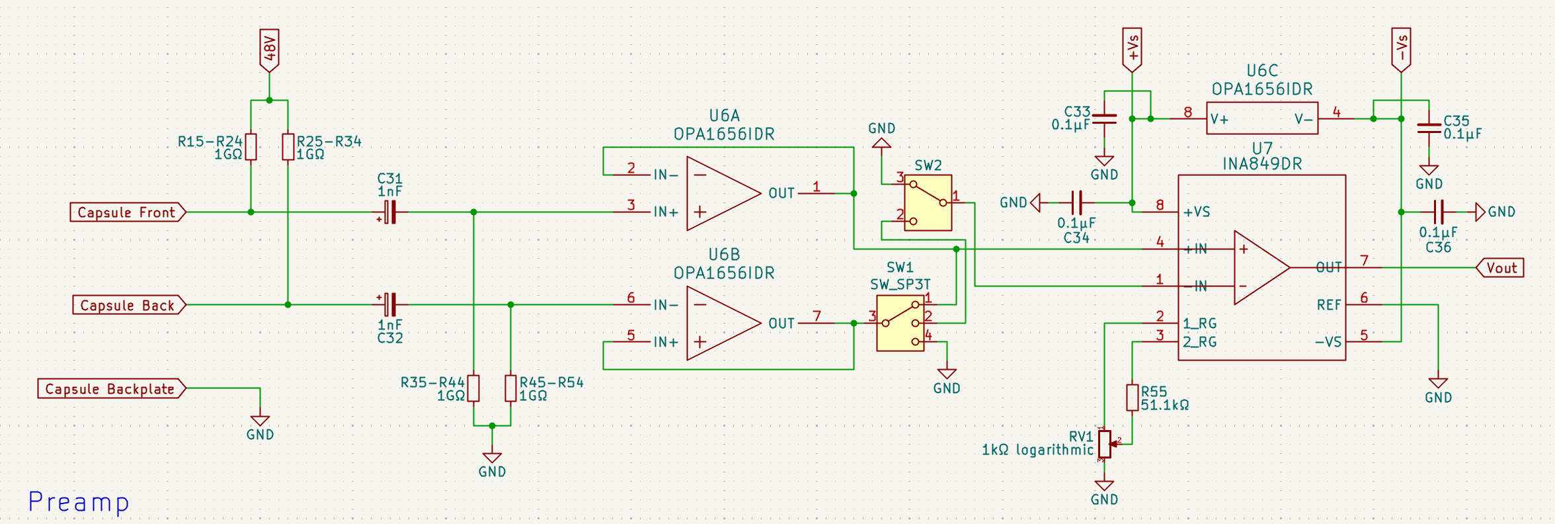
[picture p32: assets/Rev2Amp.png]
 

Secondly, I caught *more than a few* miscalculations in the resistor values for some of the power components and fixed them. I've also moved from using two LT4035's to only 1 as after calculating the total power draw, one will be sufficient.
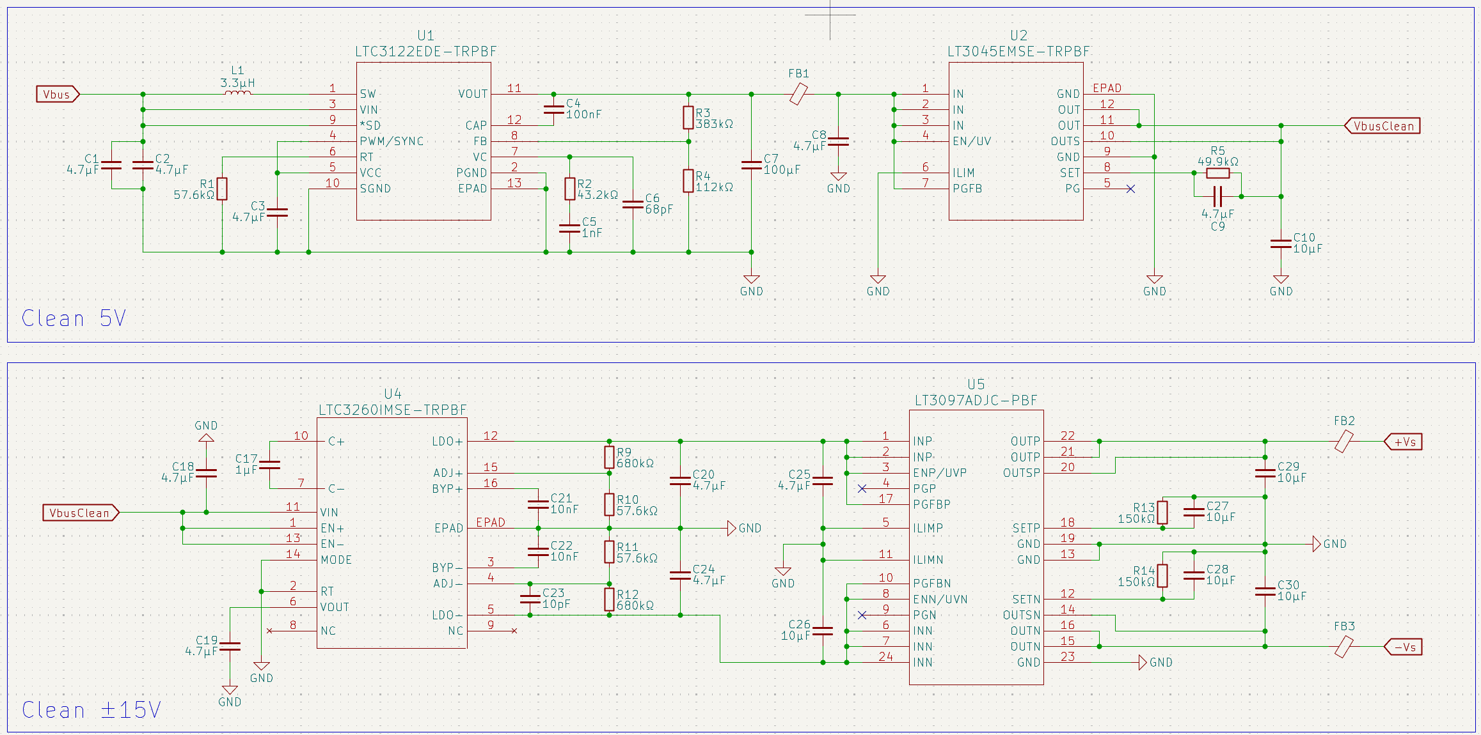
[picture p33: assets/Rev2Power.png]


The bigger change, however, is a with the ADC. I've decided to completely remove the PCM2900. Its just not good enough, and it would be a shame to pair it with the analog front-end. The new plan is to use a dedicated ADC, then over I2S or some other protocol with a STM32 or similar, bridge it to USB. Which means the project just got a lot more complicated-

**Time spent: 3hrs*

## June 1st
Some more work on the mic today! Attempted implementing the PCM2900 to take the line-level signal and output USB. I've also printed (yes printed) the datasheets for all my power components so I can go through and check for errors sometime next week.
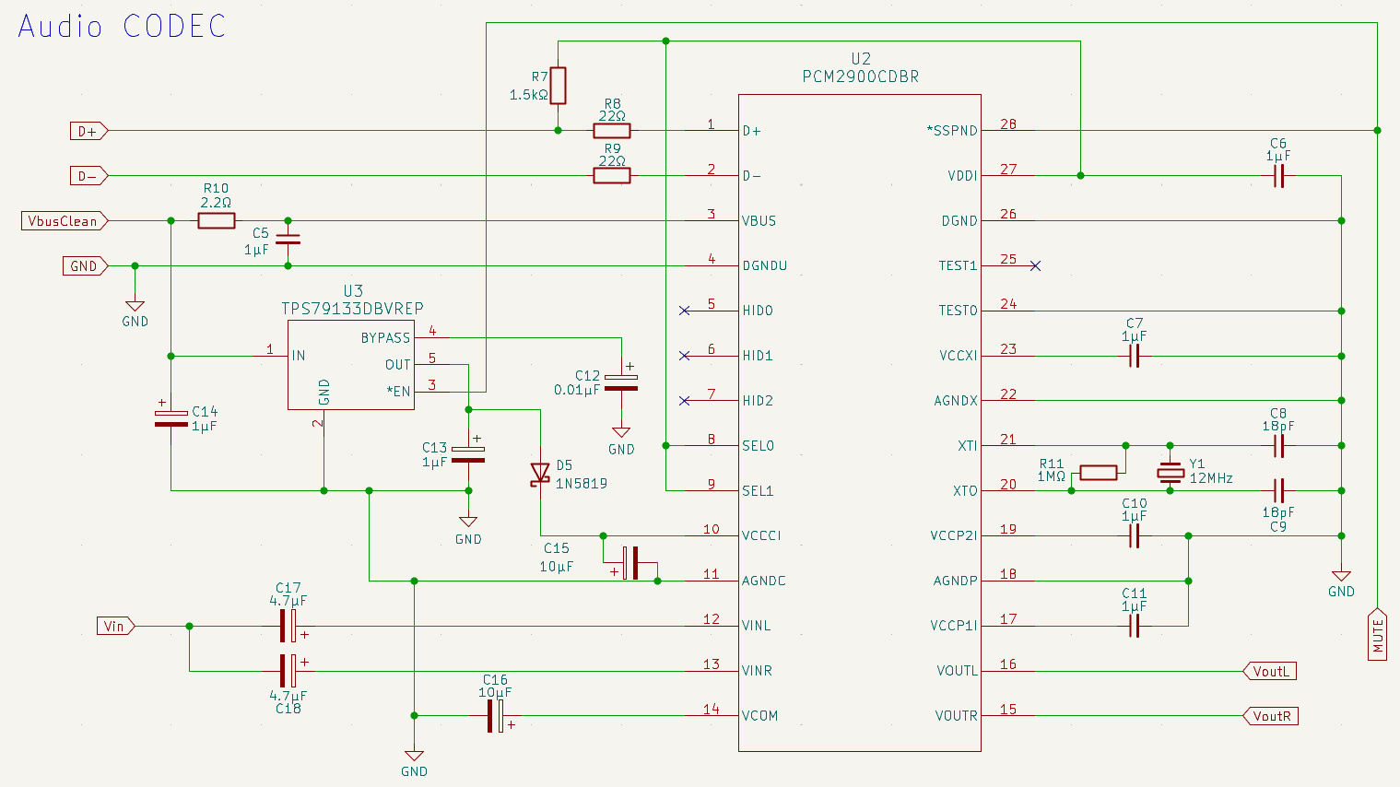
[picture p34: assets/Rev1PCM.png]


**Time spent: 1hr**

## May 28th, 29th, 30th
A bit of work on the schematics over the last few days - been caught up with Hackpad as well as my DLSR Gimbal though. First up was the capsule and preamp - I primarily looked at some example implementations in TI datasheets. Here it is!
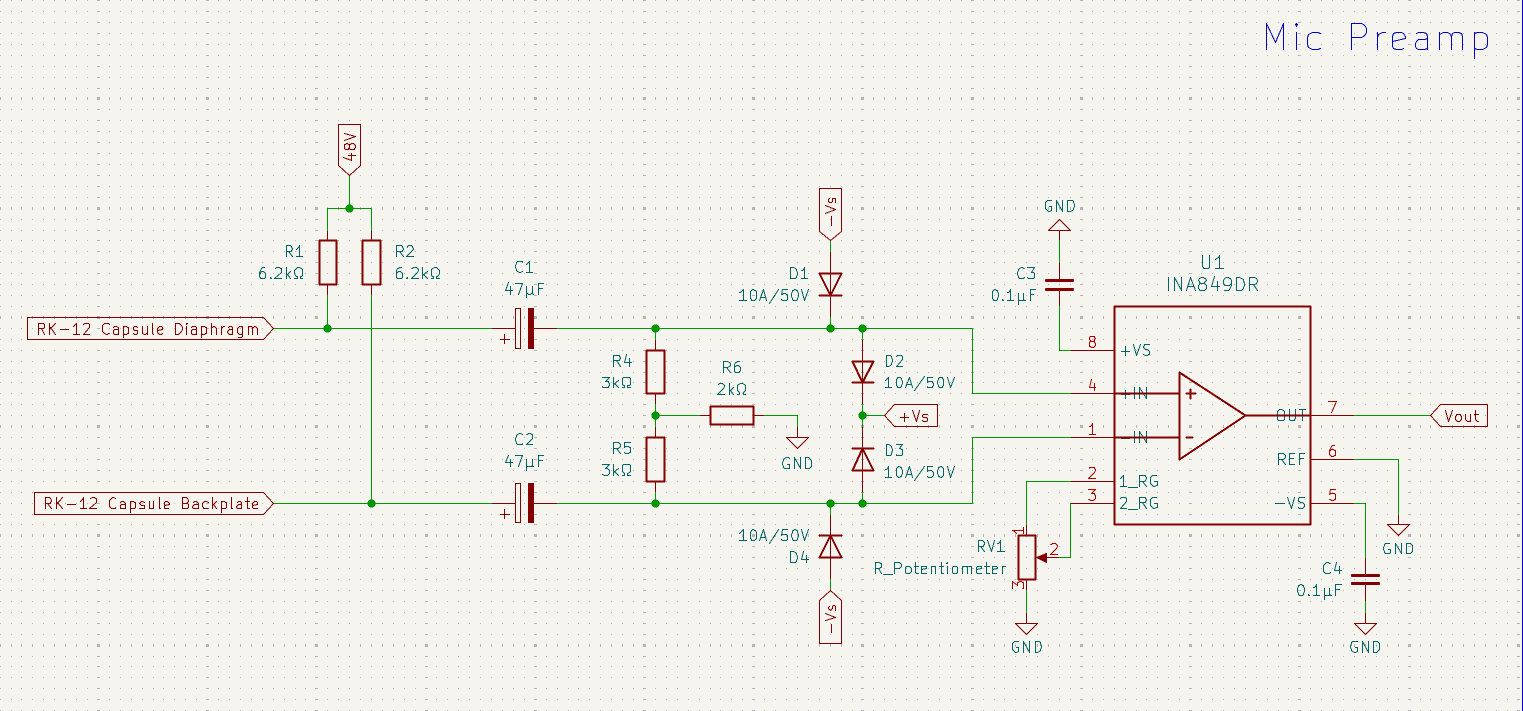
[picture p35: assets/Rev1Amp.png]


Still not too sure how much of it works... I'll keep it the same as the TI implementation for now until I know how any of it works. 

Next up was the power circuitry - it's a bit of a headache but I'll try to explain the basics of each stage.

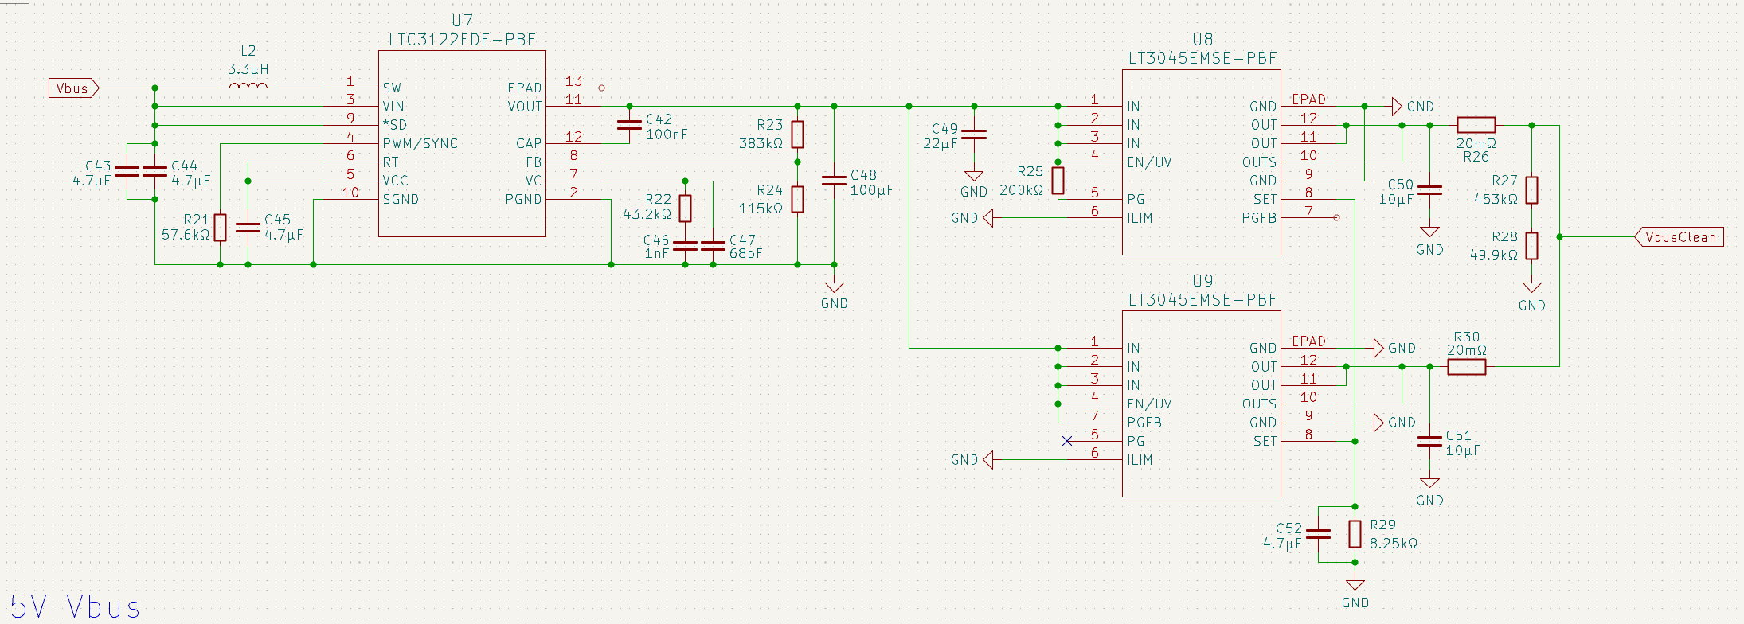
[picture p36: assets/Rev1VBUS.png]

First up here are the components to filter the noisy (and not actually 5V) Vbus from the usb host (laptop). The basic outline for this stage is to take the 4.45V-5.25V, boost it up to slightly over 5V, and the drop it to a nice and clean 5V with a LDO.

Schematic
VERY SIMILAR TO THE ONE ABOVE. Takes the clean 5V in, and spits out ±15V (just think of it as 30V but GND is now in the middle) which does through a LDO that supports a pos and neg voltage.

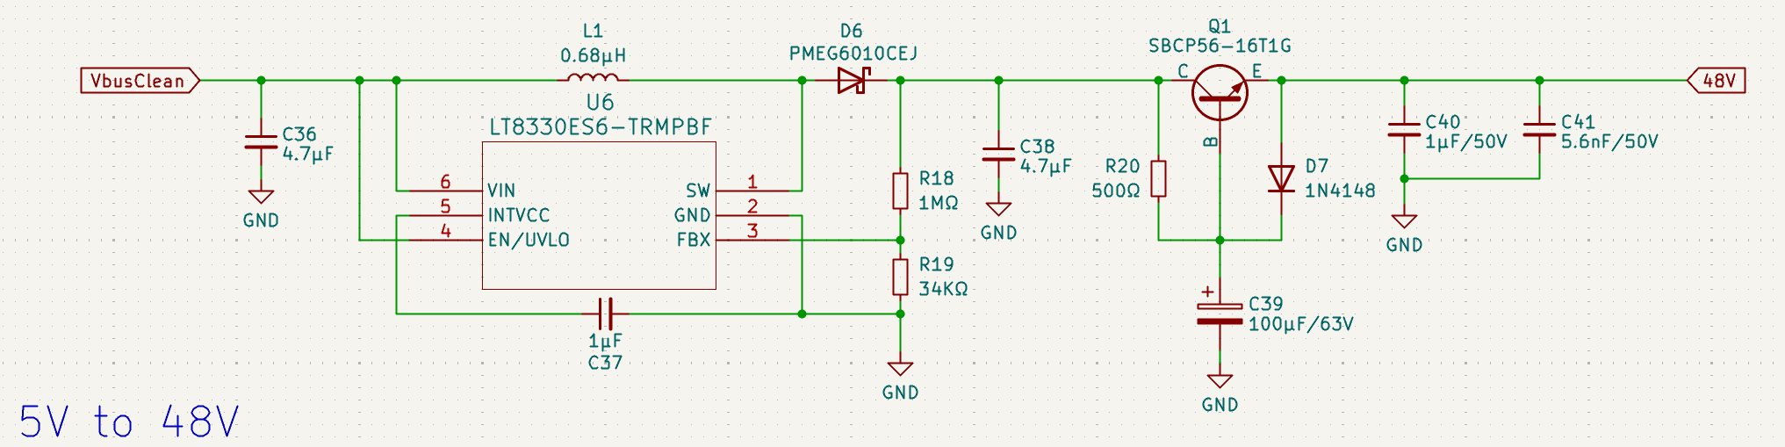
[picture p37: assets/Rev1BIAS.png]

This one's actually from a old THAT Corp. blog post, saves some trouble looking for components (saving a little cost) while also providing me with a schematic I know works! 

Overall, progress going pretty well~

**Time spent: 8hrs**

## May 26th, 27th - Final research
Yes I've run out of title ideas...

I'm combining multiple days in the logs because I've just started another project [here](https://highway.hackclub.com/projects/ConfusedHello/DLSR-Gimbal) but we'll make sure to keep going here!

Majority of the last two days has been finding suitable components for the main stages of the mic board. This took so long I feel like I've memorised parts of the TI and AD websites by now. The components I've chosen for now are:

- INA849DR amp
- LTC3265 + LT3097 for 5V to ±15V, then a ±15V LDO
- LTC3122 + LT3045 for Vbus to 5V, then a 5V LDO
- LT8330 for 48V

Interestingly, something I found while scouting the TI website is the PCM2900. It's a single chip that combines an ADC and a USB controller. It's slightly limiting at 16bit/48kHz but let's go with it for now.

**Time spent: 8hrs**

## May 24th, 25th - Let There Be 48V
Finished the initial research phase. so much information on power supply design/components. Powering sensitive analog circuits from a noisy 5V USB line (and oml it's so much worse than I expected) is a major challenge. For PSU components, values such as Power Supply Rejection Ratio (PSRR) etc. are crucial for a clean sound. 

In summary, the power will go through a buck/boost converter to get a stable 5V, and then will be followed by a low-dropout (LDO) regulator to clean it up. The LDOs I'm looking at (LTC3045 for example) have a very low noise level to ensure the preamp gets the clean power it needs to perform well.

As the 48V for the bias voltage from 5V requires a significant step-up, I found a great reference design in an old blog post from THAT Corporation that uses an LTC boost controller.

Design begins tomorrow!

**Time spent: 10hrs**

## May 23rd - And Then God Said, Let There Be Sound
Today's research was focused mostlyy on taking the output of the capsule and turning it into a line-level signal through something called a preamp stage. As a true condenser capsule has an incredibly high output impedance (typically in the GOhm range), and has tinyy fuctuations when in use, you need to amplify the signal before processing it digitally.

Most of the day was spent reading application notes from TI, Analog Devices, and THAT Corp (yes, THAT one) and looking into some existing DIY microphone designs, either way I'm pretty sure I'm in for a world of pain. Already thinking of some components for the device.

**Time spent: 5hrs**

## May 22nd - In the Beginning, There Was Nothing
Beginning work on the project today! The main inspiration is the DIY Perks USB Mic, but I want to go a step further and build one for myself while understanding the theory behind a mic. First decision - the capsule. I've settled on a RK-12 style knockoff off AliExpress that looks promising.
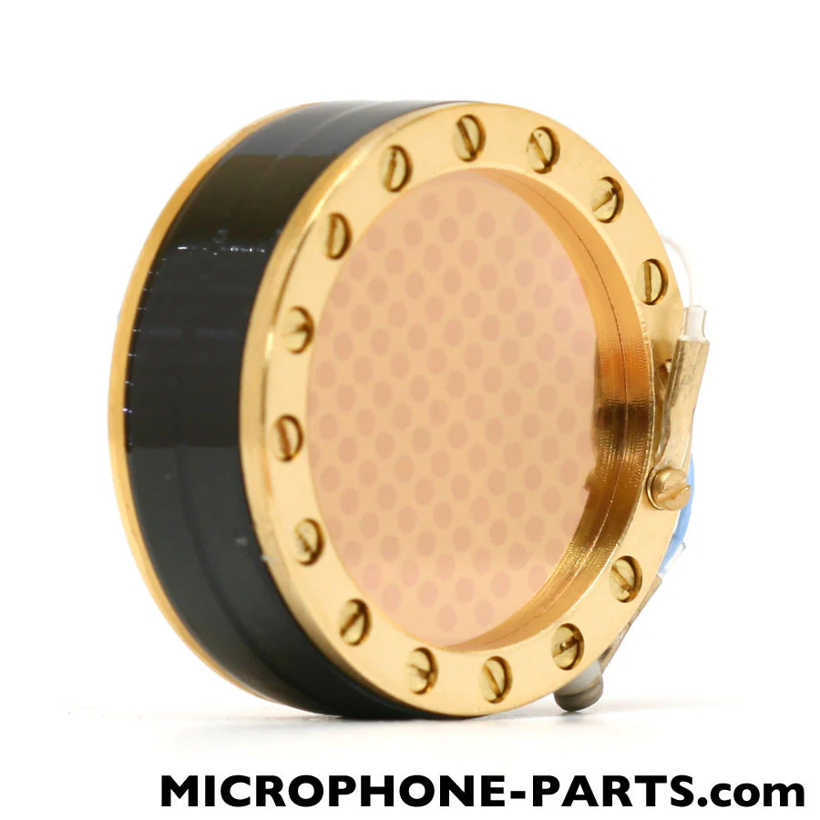
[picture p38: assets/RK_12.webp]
RK-12 Capsule


It's dual diaphram (as far as I can tell) with a single blackplate in the middle. This does mean however I will be building proper a high-voltage bias supply and proper preamp.

So what's the difference between my project and your standard DIY Mic? Well, it's going to be USB, while majority of DIY mics are XLR (saves the pain of USB stuff and other amp issues). Anyways, I'm expecting the next few days to be insane amounts of research considering... mic design has quite the learning curve apparently.

**Time spent: 4hrs**

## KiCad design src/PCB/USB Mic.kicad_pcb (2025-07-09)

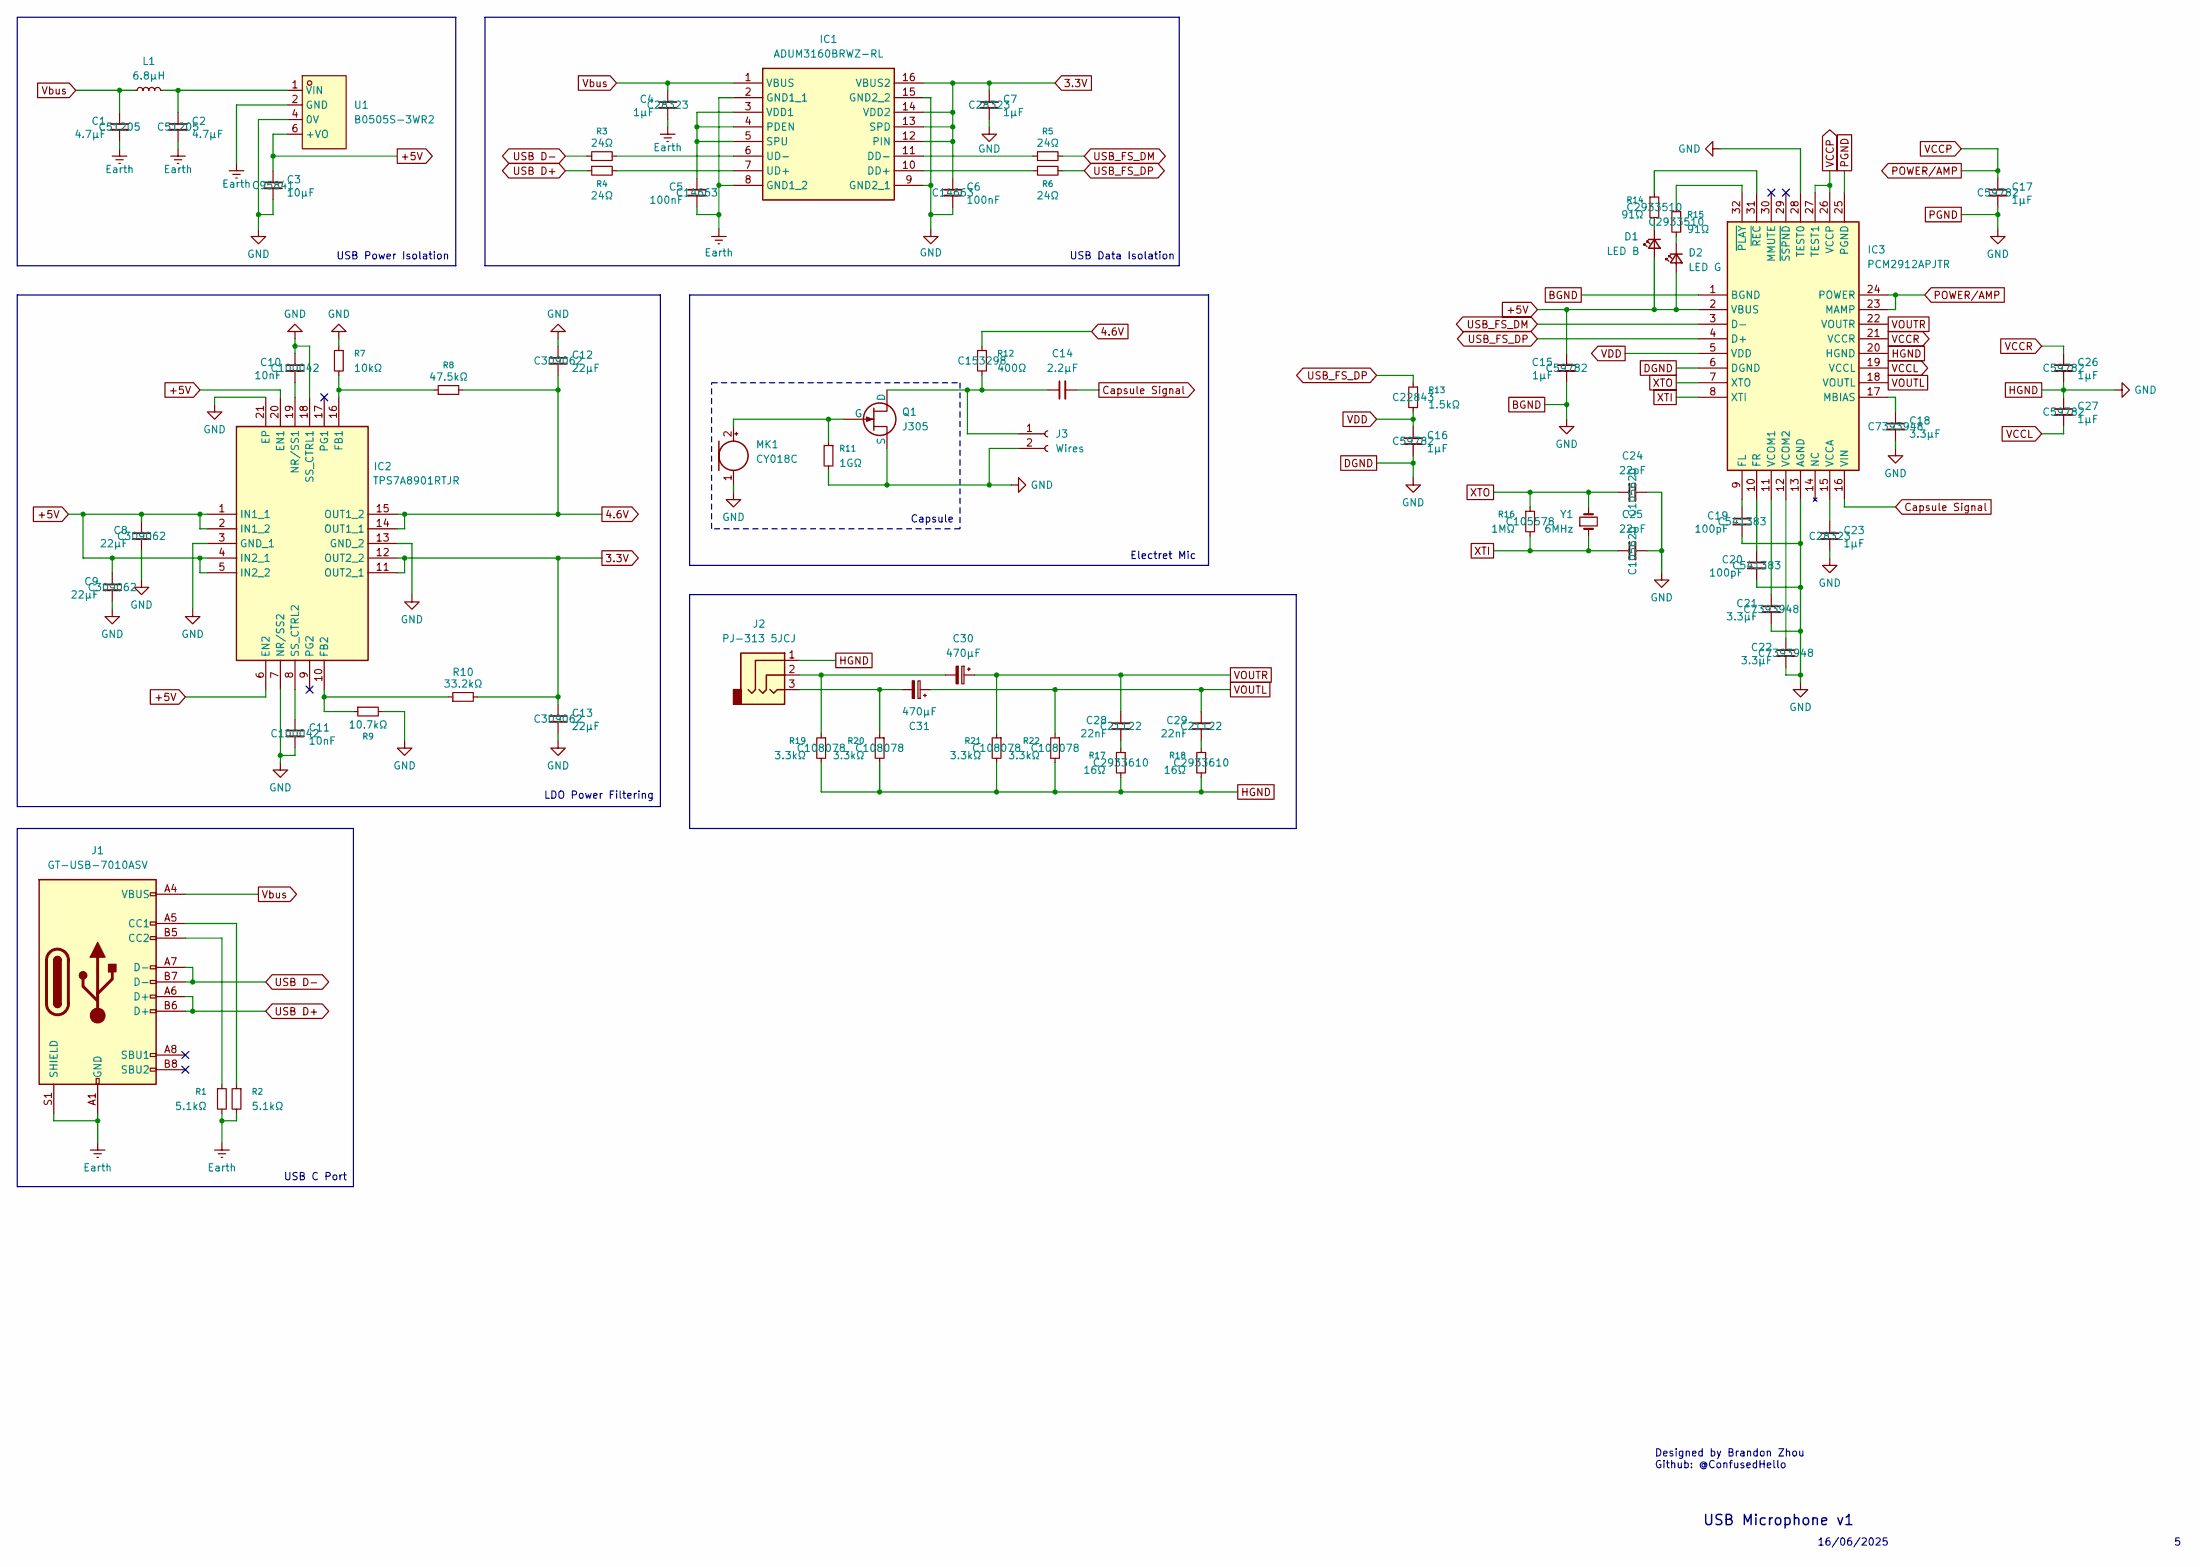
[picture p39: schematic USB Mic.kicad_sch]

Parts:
C1, C2: 4.7µF; C_1206_3216Metric_Pad1.33x1.80mm_HandSolder; LCSC C51205
C3: 10µF; C_0805_2012Metric_Pad1.18x1.45mm_HandSolder; LCSC C95841
C4, C7, C23: 1µF; C_0805_2012Metric_Pad1.18x1.45mm_HandSolder; LCSC C28323
C5, C6: 100nF; C_0603_1608Metric_Pad1.08x0.95mm_HandSolder; LCSC C14663
C8, C9, C12, C13: 22µF; C_1210_3225Metric_Pad1.33x2.70mm_HandSolder; LCSC C309062
C10, C11: 10nF; C_0603_1608Metric_Pad1.08x0.95mm_HandSolder; LCSC C100042
C14: 2.2µF; CAP-TH_L17.5-W10.0-P15.00-D1.2; LCSC C178482
C15, C16, C17, C26, C27: 1µF; C_0603_1608Metric_Pad1.08x0.95mm_HandSolder; LCSC C59782
C18, C21, C22: 3.3µF; C_0805_2012Metric_Pad1.18x1.45mm_HandSolder; LCSC C7393948
C19, C20: 100pF; C_0402_1005Metric_Pad0.74x0.62mm_HandSolder; LCSC C541383
C24, C25: 22pF; C_0603_1608Metric_Pad1.08x0.95mm_HandSolder; LCSC C105620
C28, C29: 22nF; C_0603_1608Metric_Pad1.08x0.95mm_HandSolder; LCSC C21122
C30, C31: 470µF; CAP-SMD_BD10.0-L10.3-W10.3-LS11.0-FD-1; LCSC C454276
D1: LED B; LED_0603_1608Metric_Pad1.05x0.95mm_HandSolder; LCSC C965807
D2: LED G; LED_0603_1608Metric_Pad1.05x0.95mm_HandSolder; LCSC C965804
IC1: ADUM3160BRWZ-RL; SOIC127P1032X265-16N; Manufacturer_Part_Number ADUM3160BRWZ-RL; LCSC C284149
IC2: TPS7A8901RTJR; QFN50P400X400X80-21N-D; Manufacturer_Part_Number TPS7A8901RTJR; LCSC C180908
IC3: PCM2912APJTR; QFP80P900X900X120-32N; Manufacturer_Part_Number PCM2912APJTR; LCSC C475497
J1: GT-USB-7010ASV; USB_C_Receptacle_G-Switch_GT-USB-7010ASV; LCSC C2988369
J2: PJ-313 5JCJ; AUDIO-TH_PJ-313_5JCJ; LCSC C668607
J3: Wires; SolderWire-0.1sqmm_1x02_P3.6mm_D0.4mm_OD1mm
L1: 6.8µH; IND-SMD_L4.0-W4.0_YHNR4020; LCSC C16197249
MK1: CY018C
Q1: J305
R1, R2: 5.1kΩ; R_0603_1608Metric_Pad0.98x0.95mm_HandSolder; LCSC C2907044
R3, R4, R5, R6: 24Ω; R_0603_1608Metric_Pad0.98x0.95mm_HandSolder; LCSC C2907018
R7: 10kΩ; R_0603_1608Metric_Pad0.98x0.95mm_HandSolder; LCSC C98220
R8: 47.5kΩ; R_0603_1608Metric_Pad0.98x0.95mm_HandSolder; LCSC C2933225
R9: 10.7kΩ; R_0603_1608Metric_Pad0.98x0.95mm_HandSolder; LCSC C5153968
R10: 33.2kΩ; R_0603_1608Metric_Pad0.98x0.95mm_HandSolder; LCSC C23003
R11: 1GΩ
R12: 400Ω; R_0805_2012Metric_Pad1.20x1.40mm_HandSolder; LCSC C153298
R13: 1.5kΩ; R_0603_1608Metric_Pad0.98x0.95mm_HandSolder; LCSC C22843
R14, R15: 91Ω; R_0805_2012Metric_Pad1.20x1.40mm_HandSolder; LCSC C2933510
R16: 1MΩ; R_0603_1608Metric_Pad0.98x0.95mm_HandSolder; LCSC C105578
R17, R18: 16Ω; R_1206_3216Metric_Pad1.30x1.75mm_HandSolder; LCSC C2933610
R19, R20, R21, R22: 3.3kΩ; R_0603_1608Metric_Pad0.98x0.95mm_HandSolder; LCSC C108078
U1: B0505S-3WR2; LCSC C7500927
Y1: 6MHz; ABLS; LCSC C596830

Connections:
3.3V: C6.1, C7.1, C13.1, IC1.12 (PIN), IC1.13 (SPD), IC1.14 (VDD2), IC1.16 (VBUS2), IC2.11 (OUT2_1), IC2.12 (OUT2_2), R10.2
4.6V: C12.2, IC2.14 (OUT1_1), IC2.15 (OUT1_2), R8.2, R12.1
+5V: C3.1, C8.1, C9.1, C15.1, D1.2 (A), D2.2 (A), IC2.1 (IN1_1), IC2.2 (IN1_2), IC2.4 (IN2_1), IC2.5 (IN2_2), IC2.6 (EN2), IC2.20 (EN1), IC3.2 (VBUS), U1.6 (+VO)
BGND: C3.2, C6.2, C7.2, C8.2, C9.2, C10.1, C11.2, C12.1, C13.2, C15.2, C16.2, C17.2, C18.2, C19.2, C20.2, C21.2, C22.2, C23.2, C24.2, C25.2, C26.2, C27.1, IC1.9 (GND2_1), IC1.15 (GND2_2), IC2.3 (GND_1), IC2.7 (NR/SS2), IC2.13 (GND_2), IC2.18 (SS_CTRL1), IC2.21 (EP), IC3.1 (BGND), IC3.6 (DGND), IC3.13 (AGND), IC3.20 (HGND), IC3.25 (PGND), IC3.28 (TEST0), J2.1, J3.2, MK1.1 (-), Q1.3 (S), R7.1, R9.2, R11.2, R17.2, R18.2, R19.2, R20.2, R21.2, R22.2, U1.4 (0V)
Capsule Signal: C14.2, IC3.16 (VIN)
Earth: C1.2, C2.2, C4.2, C5.2, IC1.2 (GND1_1), IC1.8 (GND1_2), J1.A1 (GND), J1.A12 (GND), J1.B1 (GND), J1.B12 (GND), J1.S1 (SHIELD), R1.2, R2.2, U1.2 (GND)
unnamed: C28.2, R17.1
unnamed: C29.2, R18.1
unnamed: C30.2, J2.2, R19.1
unnamed: C31.2, J2.3, R20.1
unnamed: D1.1 (K), R14.2
unnamed: D2.1 (K), R15.2
unnamed: IC1.10 (DD+), R6.1
unnamed: IC1.11 (DD-), R5.1
unnamed: C5.1, IC1.3 (VDD1), IC1.4 (PDEN), IC1.5 (SPU)
unnamed: IC1.7 (UD+), R4.2
unnamed: IC1.6 (UD-), R3.2
unnamed: IC2.16 (FB1), R7.2, R8.1
unnamed: IC2.10 (FB2), R9.1, R10.1
unnamed: C10.2, IC2.19 (NR/SS1)
unnamed: C11.1, IC2.8 (SS_CTRL2)
unnamed: C19.1, IC3.9 (FL)
unnamed: C20.1, IC3.10 (FR)
unnamed: C18.1, IC3.17 (MBIAS)
unnamed: C23.1, IC3.15 (VCCA)
unnamed: C21.1, IC3.11 (VCOM1)
unnamed: C22.1, IC3.12 (VCOM2)
unnamed: IC3.32 (~PLAY), R15.1
unnamed: IC3.31 (~REC), R14.1
unnamed: J1.A5 (CC1), R2.1
unnamed: J1.B5 (CC2), R1.1
unnamed: C14.1, J3.1, Q1.1 (D), R12.2
unnamed: MK1.2 (+), Q1.2 (G), R11.1
unnamed: C2.1, L1.2, U1.1 (VIN)
POWER/AMP: C17.1, IC3.23 (MAMP), IC3.24 (POWER), IC3.26 (VCCP), IC3.27 (TEST1)
USB D+: J1.A6 (D+), J1.B6 (D+), R4.1
USB D-: J1.A7 (D-), J1.B7 (D-), R3.1
USB_FS_DM: IC3.3 (D-), R5.2
USB_FS_DP: IC3.4 (D+), R6.2, R13.1
VCCL: C27.2, IC3.19 (VCCL)
VCCR: C26.1, IC3.21 (VCCR)
VDD: C16.1, IC3.5 (VDD), R13.2
VOUTL: C29.1, C31.1, IC3.18 (VOUTL), R22.1
VOUTR: C28.1, C30.1, IC3.22 (VOUTR), R21.1
Vbus: C1.1, C4.1, IC1.1 (VBUS), J1.A4 (VBUS), J1.A9 (VBUS), J1.B4 (VBUS), J1.B9 (VBUS), L1.1
XTI: C25.1, IC3.8 (XTI), R16.2, Y1.1
XTO: C24.1, IC3.7 (XTO), R16.1, Y1.2

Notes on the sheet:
Electret Mic
Designed by Brandon Zhou Github: @ConfusedHello
USB C Port
USB Microphone v1
USB Power Isolation
16/06/2025
LDO Power Filtering
USB Data Isolation
Capsule

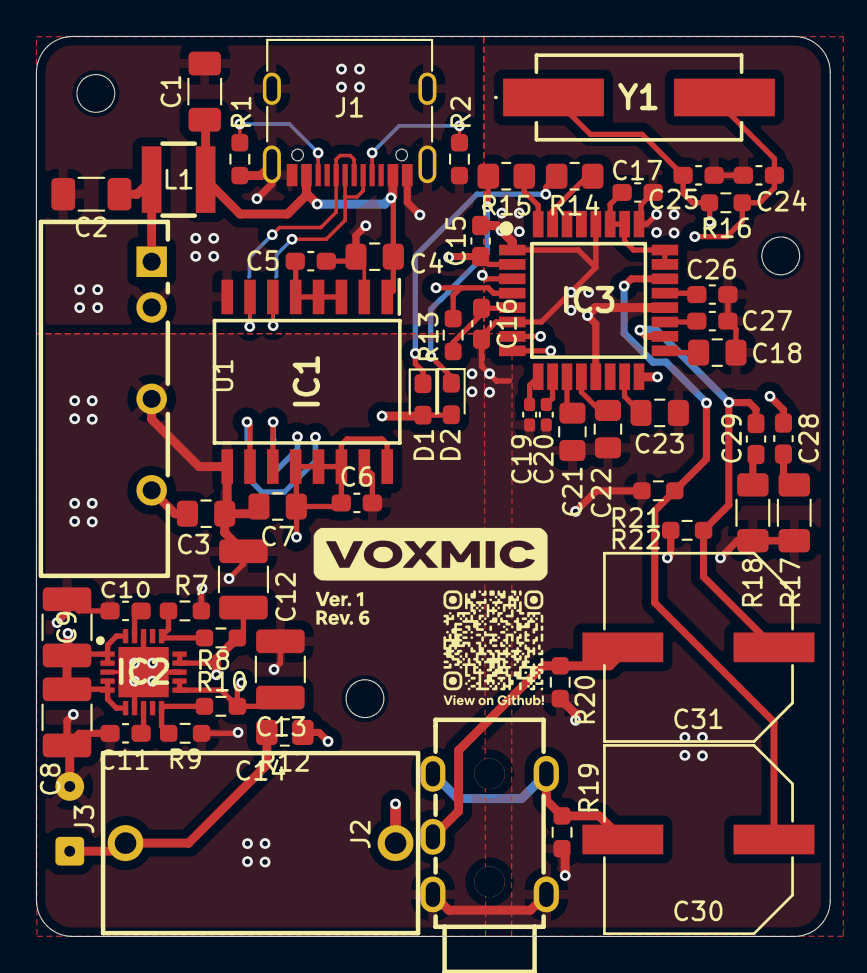
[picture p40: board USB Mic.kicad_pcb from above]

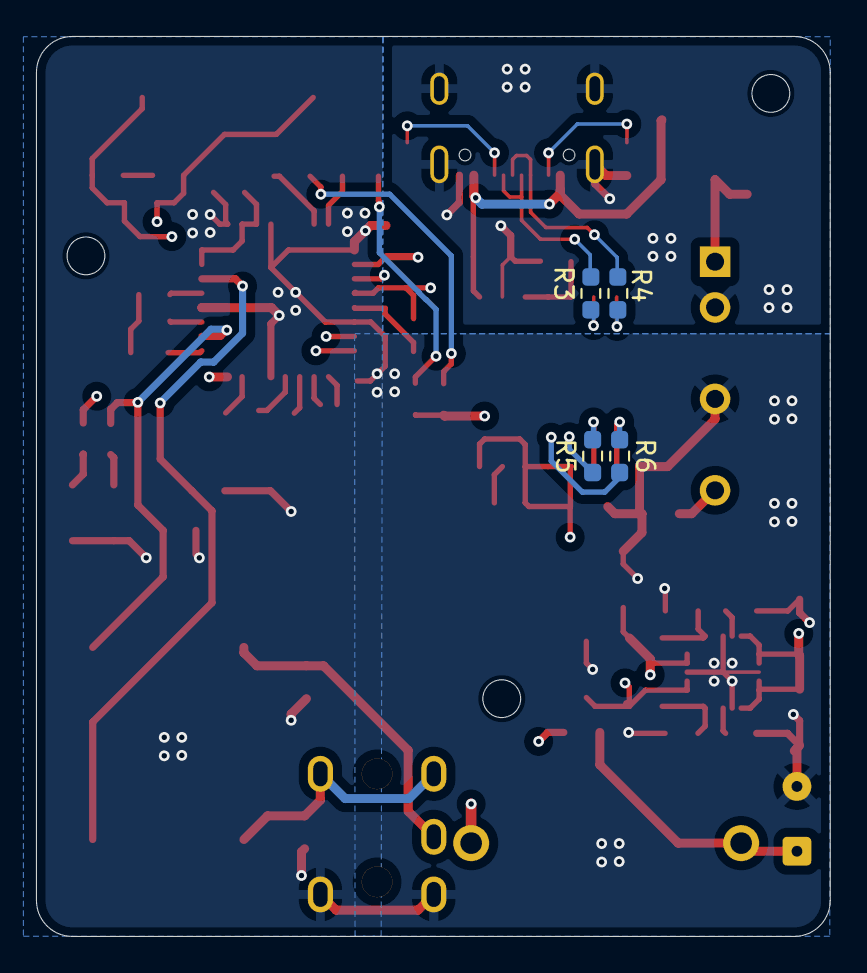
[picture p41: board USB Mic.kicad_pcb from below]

Board: 4 copper layers, 44.1 x 50.0 mm, 63 parts (4 on the bottom side), 46 nets.

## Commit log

2025-06-12 Add .gitignore for KiCad
2025-06-12 Upload Rev. 4 Schematic
    [USB Mic.kicad_pcb, USB Mic.kicad_sch]
2025-06-13 Update Rev.4 Schematic
    [USB Mic.kicad_sch]
2025-06-18 Upload SPICE and update schematic
    [USB Mic.kicad_sch]
2025-06-20 Update to Rev. 5
    [USB Mic.kicad_sch]
2025-07-09 Finalise PCB
    [ABLS2-6.000MHZ-D4Y-T.stp, ADUM3160BRWZ-RL.stp, AUDIO-TH_PJ-313_5JCJ.step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]
2025-07-09 Fix BOM
2025-07-10 Upload KiCad 3D model
2025-07-19 Fix KiCad .csv gitignore issue
2025-07-19 Upload BOM files
    [BOM.csv, Capsule.csv, PCB.csv]
